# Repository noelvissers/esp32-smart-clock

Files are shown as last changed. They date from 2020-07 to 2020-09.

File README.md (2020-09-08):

# Smart Clock





The 'Smart Clock' is a clock that displays time, date and weather information. It can auto change display brightness and almost everything is configurable (like 12-hour or 24-hour clock, temperature in °C or °F, date in days-months or months-days format and automatic or manual brightness control).  
Hardware files are made in Altium and software is written in C++.

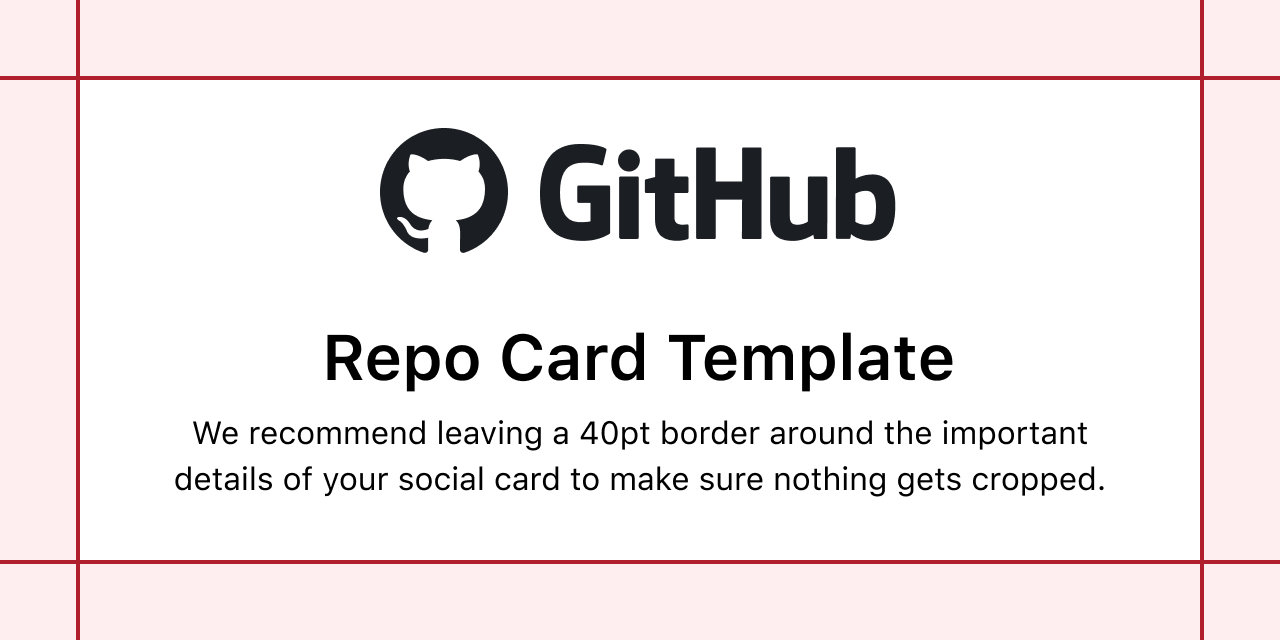
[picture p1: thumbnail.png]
Smart Clock


'Smart Clock' is a project I started years ago with an idea for my Arduino Nano after seeing [this](https://www.instructables.com/id/Making-a-Wooden-LED-Clock/) project. I got the basics to work but wanted to expand and improve on this idea.
A lot more was possible with wifi integration on the ESP32, so that's what made me pick up this project again. I'm most interested in hardware (that's also what I studied) but during this project I learned a lot about C++ in general, so it was a good learning experience. I know the code can get a lot cleaner if I remove some global vars and structure some things a bit different, but I found a lot of that out while already being pretty far into the project. Maybe something to change in the future, but not for now.

## Table of content
- [Project directories](#project-directories)
- [Features](#features)
- [Software](#software)
  * [Language](#language)
  * [IDE and framework](#ide-and-framework)
  * [Libraries](#libraries)
  * [Documentation](#documentation)
- [Hardware](#hardware)
  * [Components](#components)
  * [PCB](#pcb)
- [Case](#case)
- [Wish list](#wish-list)

## Project directories
### `/hardware`
This directory includes all the hardware files used in this project. The .pdf files of the Smart Clock schematic and PCB design are located in the main folder. The original Altium Designer files and gerber files are located in the sub folders.
### `/include`
The include directory contains all the header files needed for this project. 
### `/src`
The src directory contains all the `.cpp` files needed to run this project, including the `main.cpp` file.

## Features
I called this project 'Smart Clock' but what does this exactly mean for this project? The clock is 'smart' in a way that it does a lot of things automatically, without the need of any user input. This results to the following features: 
- Displaying time and weather information   
Of course, the most important feature of a clock: Displaying the time. Besides displaying time, the Smart Clock can display date, temperature, humidity and time with date in binary (when enabled and always in 24H format).   
   
   ![Different modes gif]()   

- Automatic network configuration:   
The clock can automatically connect to a saved wifi network. When there is no network configured, it sets up its own network to connect to via your PC, tablet or phone. A new wifi connection can be configured in the portal that shows up after connecting. The settings of the clock can also be configured in this portal as shown below:   
   
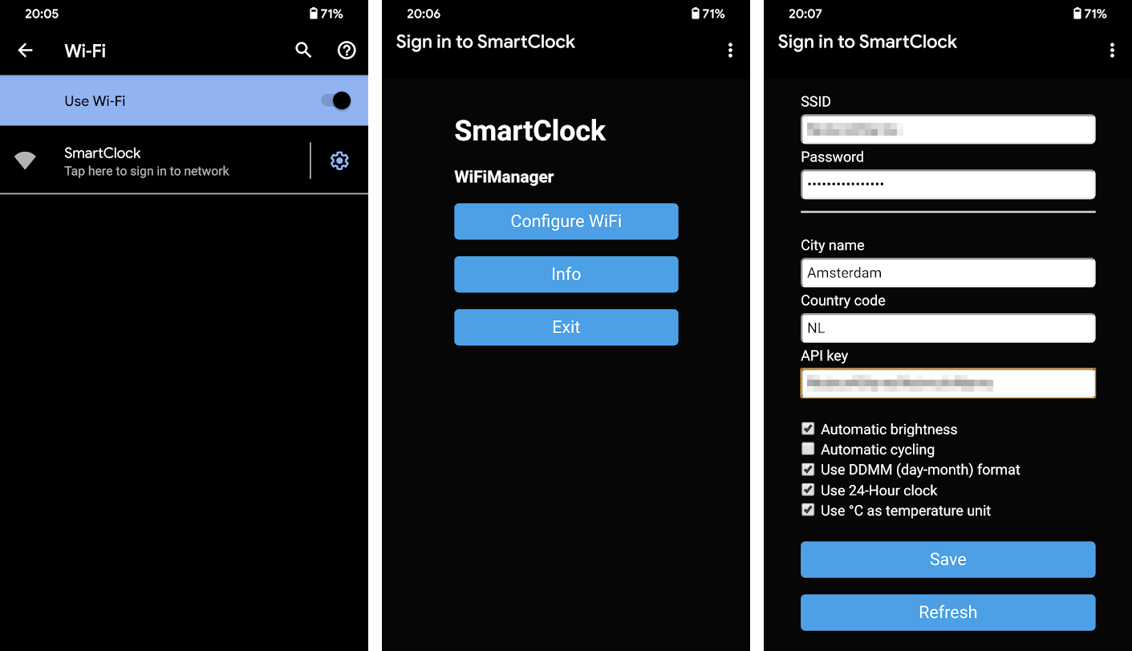
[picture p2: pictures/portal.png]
Configuration portal
      

- As shown in the portal, the clock has a lot of different settings:
   - **Auto brightness**: Automatically change the brightness of the matrix display depending on the light level in the room. This can also be manually controlled with the buttons on top of the clock (this will disable auto brightness and can be enabled again by holding the '+' button). Sensitivity can be adjusted in software, and with the potentiometer on the PCB.
   - **Auto cycling**: Auto cycle between the different screens like time, date and weather information. This can also be manually done by pressing the middle button on the clock. Doing this will disable auto cycling. To enable this again, hold the '-' button.
   - **Clock format**: Choose between 12-hour or 24-hour clock format.
   - **Date format**: Choose between Day-Month format or Month-Day format.
   - **Temperature unit**: Choose between °F or °C. 
   - **City/Country**: Get accurate weather information from your specified location. Check the available locations and valid format [here](https://openweathermap.org/).
- The RTC is synced with the web. This means if for some reason the RTC gets out of sync, the right time is set based on your [IP/location](http://worldtimeapi.org/api/ip).   

## Software
### Language
This project is written in C++ on the Arduino framework using PlatformIO. 
### IDE and framework
- [Visual Studio Code](https://code.visualstudio.com/) (Free)
- [PlatformIO for VSCode](https://platformio.org/install/ide?install=vscode) (Extension for VSCode. This basically is a fancy Arduino IDE and I recommend it for everyone programming an Arduino or using the Arduino platform since it's way more user and debug friendly)
- [Tutorial for using PlatformIO with ESP32](https://docs.platformio.org/en/latest/tutorials/espressif32/arduino_debugging_unit_testing.html)
### Libraries   
Libraries are automatically downloaded when building the project. They are defined in `platformio.ini`.
- [LedControl](https://github.com/gordoste/LedControl)
- [ArduinoJson](https://github.com/bblanchon/ArduinoJson)
- [RTClib](https://github.com/adafruit/RTClib)
- [WiFiManager](https://github.com/tzapu/WiFiManager#development) (development branch)
### Documentation
See comments in source files for the explanation of the code. If you have any questions about the code, or anything else, you can make an [issue](https://github.com/noelvissers/esp32-smart-clock/issues) and I'll try to answer it as soon as I can.

## Hardware
The whole project is built on the ESP32. The board I used is the [ESP32-DevKitC V4](https://docs.espressif.com/projects/esp-idf/en/latest/esp32/hw-reference/esp32/get-started-devkitc.html). This microcontroller is easy to use (uses the Arduino framework) and has built-in bluetooth and wifi connectivity. This controller also has two cores which is very useful in some situations.
### Components   
NEEDS UPDATING!!!   
- [ESP32-WROOM-32D](https://aliexpress.com/item/4000103411061.html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,searchweb201602_,searchweb201603_)
- [Micro USB cable extender](https://aliexpress.com/item/32859863965.html?spm=a2g0s.9042311.0.0.27424c4du3jPcB)
- [USB C (F) to micro USB (M)](https://aliexpress.com/item/33004521025.html?spm=a2g0s.9042311.0.0.27424c4du3jPcB)
- 2x [Matrix display 8x8 + MAX7219](https://aliexpress.com/item/4000263982956.html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,searchweb201602_,searchweb201603_)
- 2x [Narrow 24 pin DIP socket](https://aliexpress.com/item/32866573215.html?spm=a2g0s.9042311.0.0.27424c4dnmoTWS)
- 4x [1x8 Matrix header](https://aliexpress.com/item/32847506950.html?spm=a2g0s.9042311.0.0.27424c4dnmoTWS)
- [DS3231 RTC](https://aliexpress.com/item/32822420722.html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,searchweb201602_,searchweb201603_)
- [3V3 - 5V level shifter](https://aliexpress.com/item/1972789887.html?spm=a2g0s.9042311.0.0.27424c4dnmoTWS)
- [2x10 2.54mm 90 degree Male header](https://aliexpress.com/item/32683792015.html?spm=a2g0s.9042311.0.0.27424c4dnmoTWS)
- [2x10 2.54mm  Female header](https://aliexpress.com/item/32864030298.html?spm=a2g0s.9042311.0.0.27424c4dnmoTWS)
- [5528 LDR](https://aliexpress.com/item/32760631393.html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,searchweb201602_,searchweb201603_)
- [<value> Potentiometer for LDR adjustments](https://aliexpress.com/item/4000109378348.html?spm=a2g0s.9042311.0.0.27424c4dp3I9x0)
- 4x [5mm M3 standoff](https://aliexpress.com/item/32982370726.html?spm=a2g0s.9042311.0.0.27424c4dp3I9x0)
- 4x [4mm M3 screw](https://aliexpress.com/item/4000193782706.html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)
- \+ Other various components like resistors and capacitors (see schematic).

The electronics for this project are fairly simple. I choose to use TH components instead of SMD components (and in some cases breakout boards) since these are easier to solder and replace by hand. Since this is meant as a prototype, a later version would include SMD components, no breakout or developer boards and probably JTAG programming. But this is out of my scope for this project.   
   
For the schematic and other documentation, see the [/hardware](/hardware/smart-clock/smart-clock) folder.

### PCB
Below you can see (from left to right) the top, front and side view of the PCB.   
   
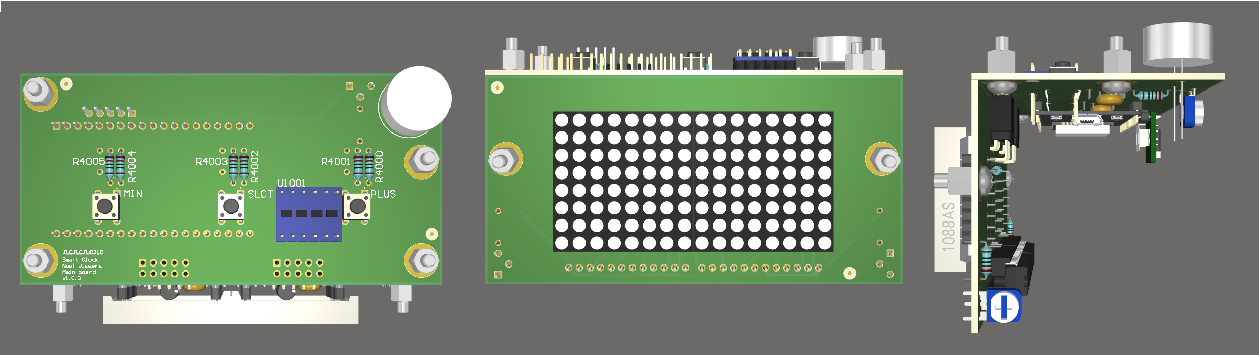
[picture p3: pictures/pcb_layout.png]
PCB
   
   
The gerber files to order the PCB are located in the designated hardware folder.
   
## Case
To see what would go where (on the PCB as well as the mechanical design) I created a [mechanical sketch](/pictures/mch_sketch.png) (yes, in paint).   
   
After this, I could make the PCB and a real mechanical drawing to figure out actual sizes of the case:   
   
MCH design   
   
After I was happy with how everything turned out, I rendered the image to get a clear view of what the end result would be like:   
   
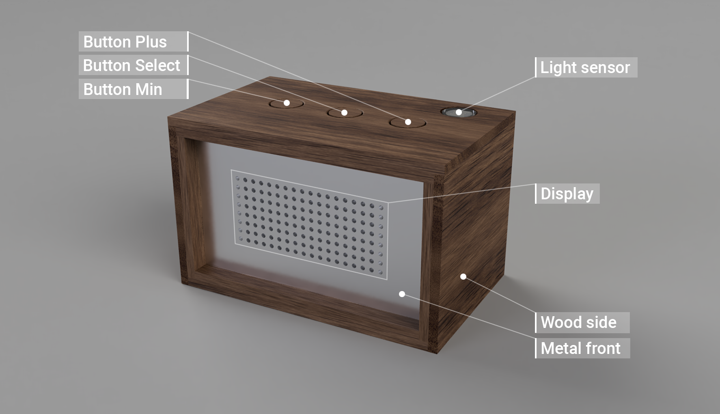
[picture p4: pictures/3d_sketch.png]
3D render
   
   
Note that there is a 8x18 grid of holes in the case, while the display is only 8x16 pixels. This (in my opinion) looks better if a digit is displayed on the edge of the display.
   
After having all the files, the PCB, all hardware components, and the software done, it was time to finish this project (v1). 

### End result
Result   

## Wish list
These are features I don't expect to implement in this version, but that could be nice for a future update.
- [x] Have wifi configurable and not hard-coded.  
- [ ] Have all the components (SMD) on 1 PCB so the whole thing can be a lot smaller. This also means not using an ESP32 dev. kit (or any USB interface at all).  
- [ ] Have an app or better online portal to configure all the settings, whenever you want (not only on startup).  
- [ ] Auto detect location to configure weather or use location from app.
- [ ] Add audio support to add alarms/mp3 playback via app.   
- [ ] Add RGB display and/or more displays, to be able to implement more features (like LaMetric Time).
- [ ] Clean up the code a lot.   
   
Feel free to submit any issues and/or pull requests if you have new idea's or run into issues. Of course, you are also free to implement idea's I mentioned.

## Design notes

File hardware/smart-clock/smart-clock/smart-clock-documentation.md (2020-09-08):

# Circuits
Below are the hardware circuits for the clock explained. If you have any questions about the circuits, or anything else, you can make an [issue](https://github.com/noelvissers/esp32-smart-clock/issues) and I'll try to answer it as soon as I can.   

Below you can see the two PCB projects, since we need two PCB's to make this clock. This is becuase the display is at a different angle (see [PCB](#pcb)).   
   
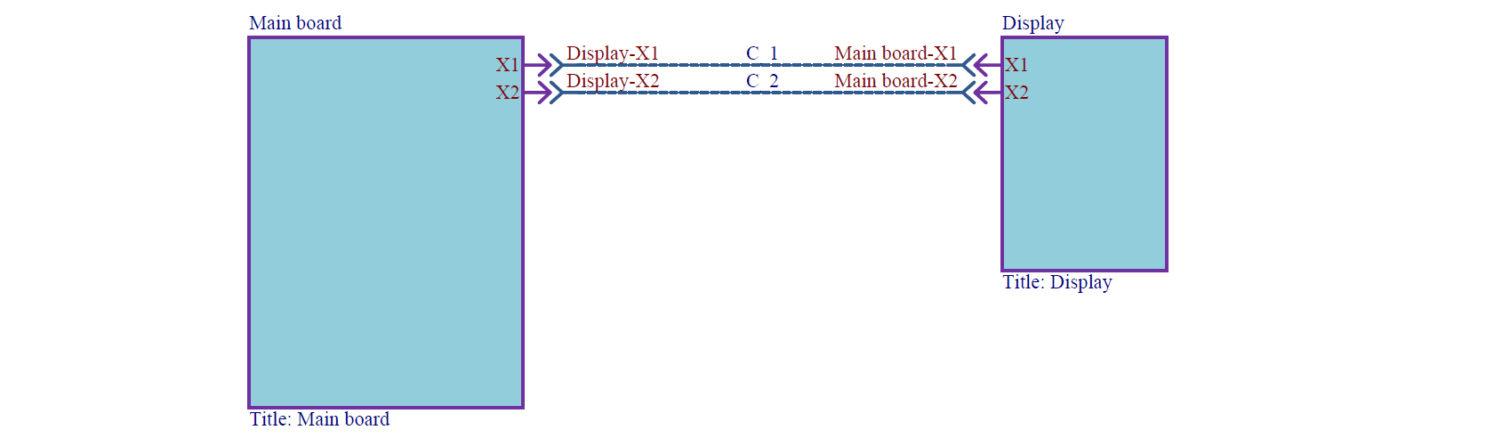
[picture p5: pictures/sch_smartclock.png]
SCH
   
   
Below you can see the schematic (blocks) for the main board. This is where most components are (outside the display). The buttons, RTC and LDR are all connected to the microcontroller, the ESP32, and the microcontroller is connected to the header that connects to the display PCB. X1 is just there for support. Note that there is no power input anywhere in these schematics. The power comes from the ESP32's USB port. This will be showed later in the mechanical design.   
   
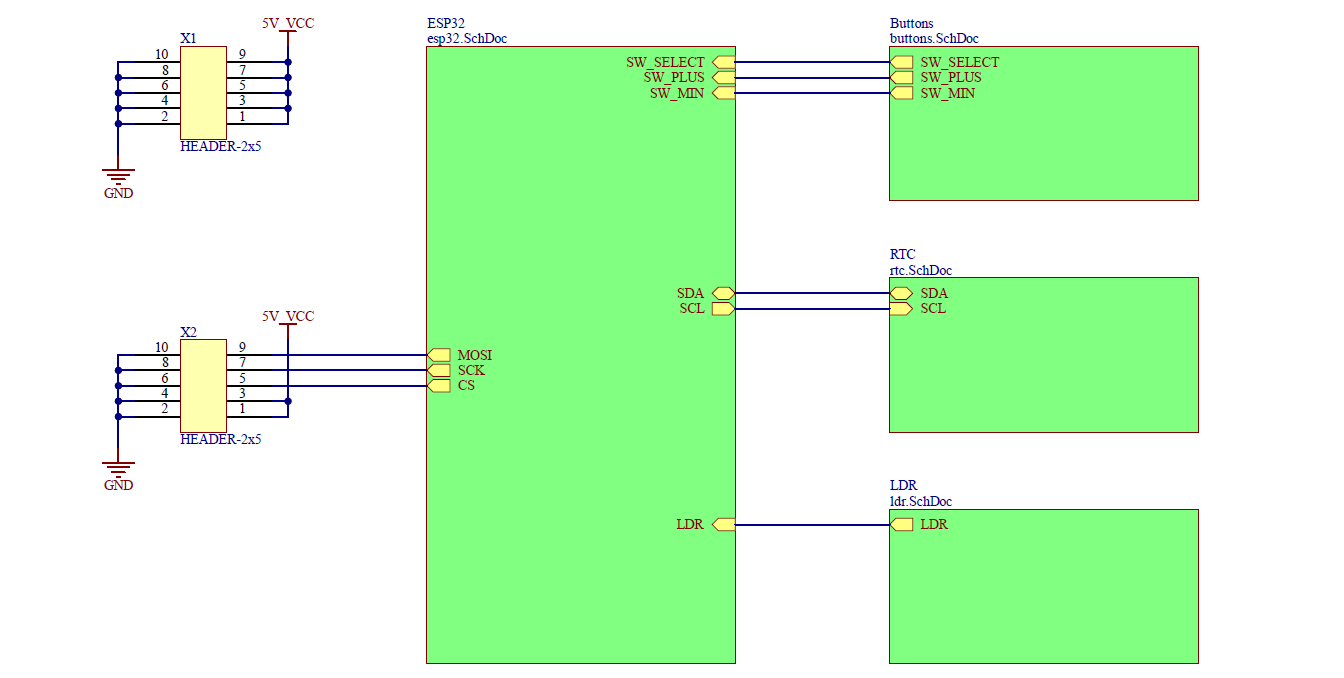
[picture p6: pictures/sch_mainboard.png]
SCH base board
  
## ESP32
This is the heart of the clock; the microcontroller a.k.a. the ESP32. Since it the operating voltage of the microcontroller is 3.3V, the normal 5V USB voltage won't be suited. On the devkit there is a voltage regulator to bring down the 5V to 3.3V, but there is still a pin we can use that is connected to the 5V input. This means we can drive the 5V display from this USB power. For the data lines we need a level shifter (U1001). This means the ESP can send on 3.3V and the MAX7219 will receive this as 5V. 
   
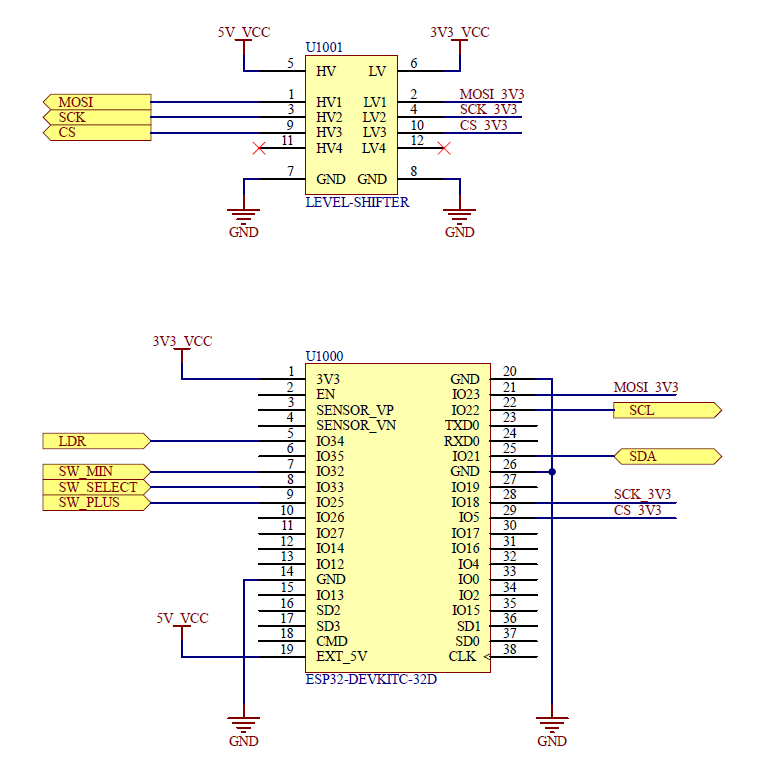
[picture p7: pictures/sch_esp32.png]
ESP32
   

## Buttons
For the buttons I used a simple debounce circuit. In testing I found out that this sometimes doesn't filter out all the bouncing, so this is also handled in software. This could be because of bad buttons or wrong resistor/capacitor values, but the solution I found in software with interrupts works very smooth right now. Having a pull-up resistor to 3.3V means the button is active LOW.   
   
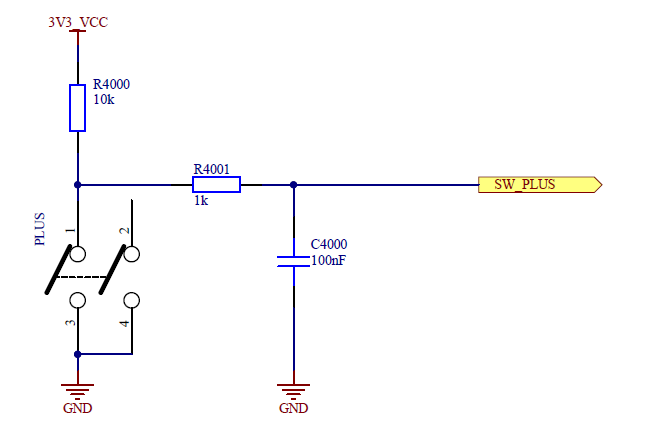
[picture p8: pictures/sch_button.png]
Buttons schematic
   

## RTC
To keep track of the time, even when the clock is powered off, we need a RTC. The DS3231 RTC used in this project communicates via I2C. This means we need 4 pins connected to the ESP: SDA, SCL and GND/VCC. The DS3231 has a [typical input voltage of 3.3V](https://datasheets.maximintegrated.com/en/ds/DS3231.pdf) which is perfect since the ESP runs on 3.3V. This also means there is no level shifter needed for the data and clock lines. Since the ESP32 has dedicated I2C pins, we can use these to communicate with the RTC. These are pin IO21 (SDA) and IO21 (SCL).   
   
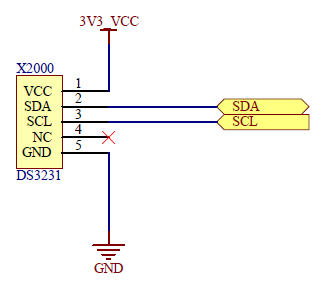
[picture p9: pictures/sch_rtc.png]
RTC schematic
   

## LDR
This is a simple voltage divider. The resistance of the LDR changes depending on the light level; more light means less resistance. This means the voltage to the analog input of the ESP changes; a higher voltage level with more light, a lower voltage level with less light. The sensitivity can be set with the potentiometer. Since this is an analog output, we need to make sure it is connected to an analog input on the ESP so we can use the ADC from the ESP to read this value.    
   
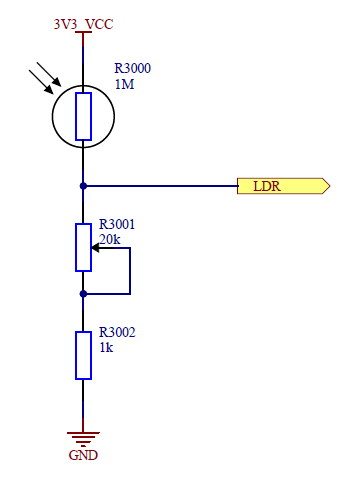
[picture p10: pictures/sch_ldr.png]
LDR schematic
   

## Display
The dot matrix displays are powered via the [MAX7219 display driver](https://datasheets.maximintegrated.com/en/ds/MAX7219-MAX7221.pdf) on 5V. Since the ESP developer board is powered by USB (5V), we can use the input voltage of the board to power the MAX7219. The other parts of ESP run on 3.3V, so we need a level shifter for the 3 data lines: D<sub>IN</sub>, CS and CLK. The CS and CLK lines go to both display 1 and 2, while the data line (D<sub>IN</sub>) only goes to display 1. The MAX7219 has a data out (D<sub>OUT</sub>) pin that can be connected to the data in pin of display 1. This way we can daisy chain the displays together.   
The I<sub>SET</sub> resistor sets the maximal current for the display. This means you will get less brightness with a higher resistor value. I found that the typical circuit that uses around 10kOhm is way too bright, especially at night. You might want to experiment with this a bit and see what value you prefer. In [this video](https://www.youtube.com/watch?v=MT4PSEJzVU0) you can see the effect of different resistor values, although a camera always tries to compensate for this light level. This video does however give a good indication of the minimum brightness. I used a 100k potentiometer in series with the recommended 10k resistor, so I can tweak it after assembly, where 10k is too bright and 100k (or 110k in this case) is probably too dark. So somewhere in the middle should be the sweat spot.   
   
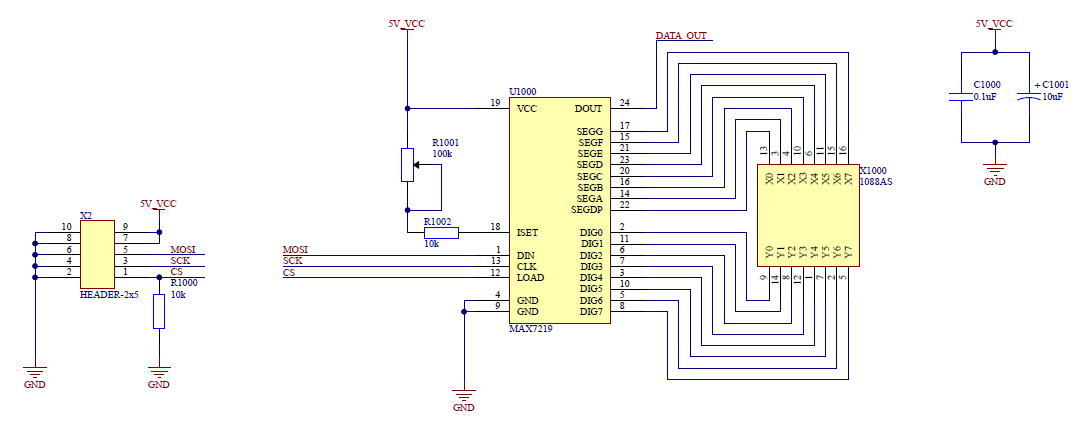
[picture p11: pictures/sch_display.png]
Display schematic
   

# Testing
Testing all the hardware (and also software). This is to check if all the circuits work as intented.   
   
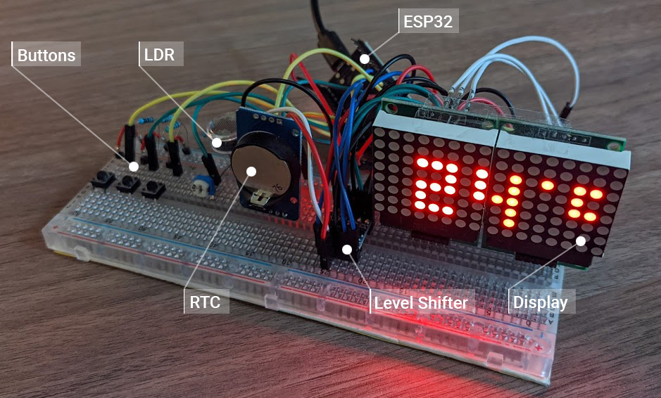
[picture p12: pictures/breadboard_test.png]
Breadboard testing
   
   
As you can see, the right display has a different brightness. During the testing phase, I found out the display can actually get pretty bright and also blinding. So I expirimented with different resistor values.

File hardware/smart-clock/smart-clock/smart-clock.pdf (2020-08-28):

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
1 | 1
2 | 2
3 | 3
4 | 4

Main board

Title: Main board

Display

Title: Display

X1 | X1
X2 | X2
Display-X1 | C_1 | Main board-X1
Display-X2 | C_2 | Main board-X2

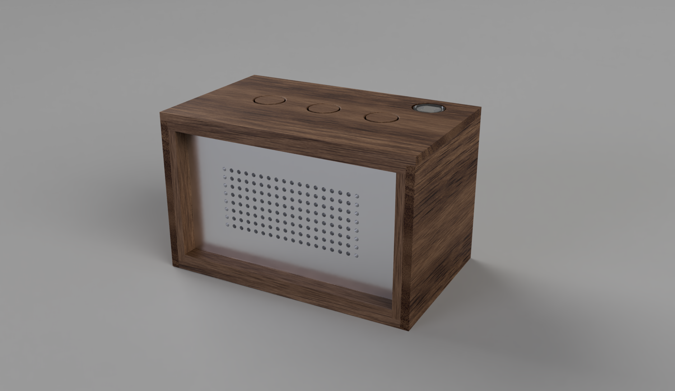
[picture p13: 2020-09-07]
pictures/3d_render.PNG

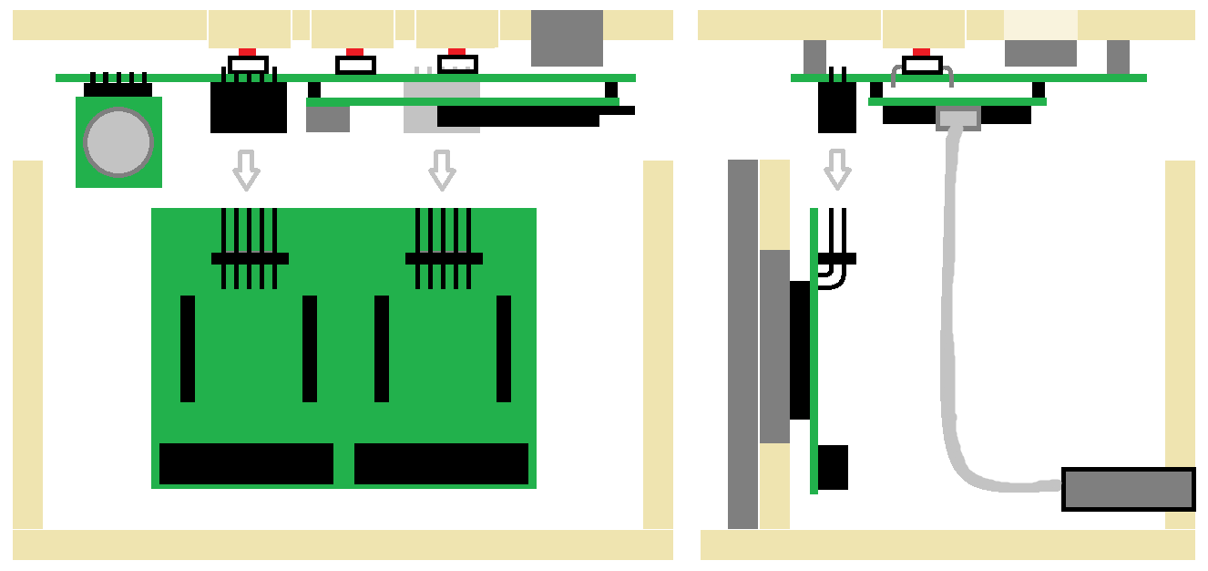
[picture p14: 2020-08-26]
pictures/mch_sketch.png

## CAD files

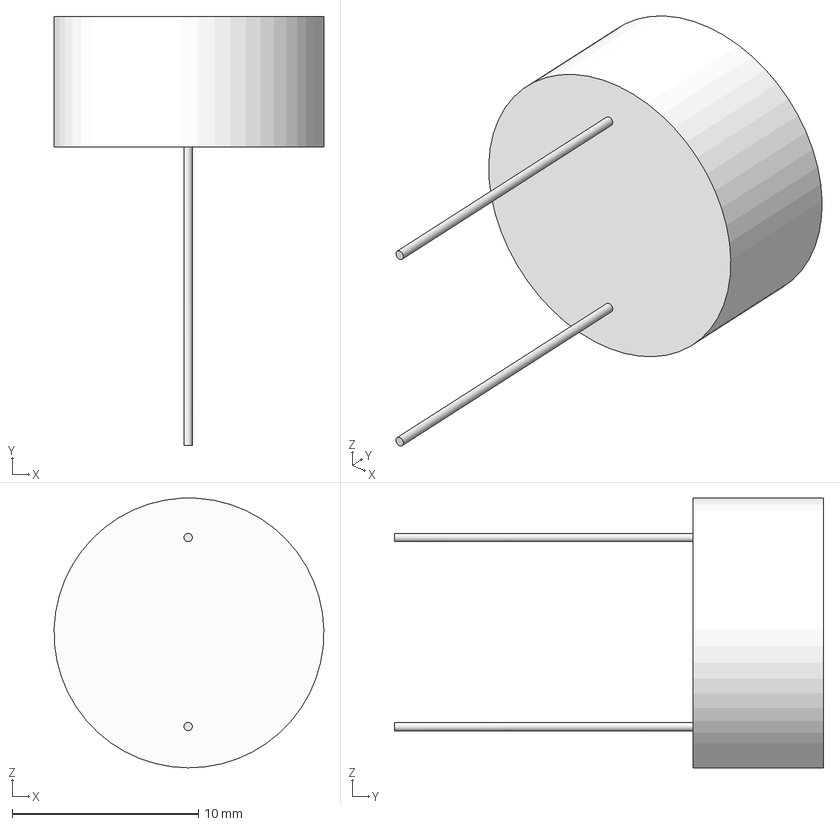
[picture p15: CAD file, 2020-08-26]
hardware/smart-clock-library/3d-files/TH LDR.step
14.5 x 23.1 x 14.5 mm
Ceramic base^LDR cell thru-hole leaded
Electrodes^LDR cell thru-hole leaded
Leads^LDR cell thru-hole leaded

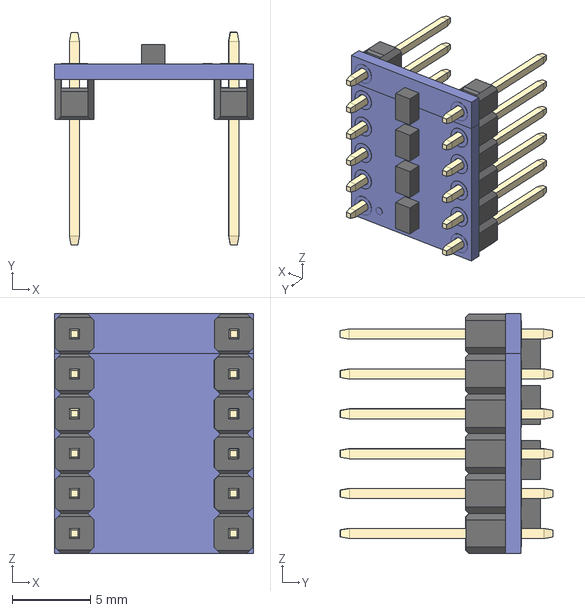
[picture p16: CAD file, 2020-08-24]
hardware/smart-clock-library/3d-files/LEVEL SHIFTER.step
12.7 x 13.6 x 15.3 mm
1x5 Male Pin Header x 2

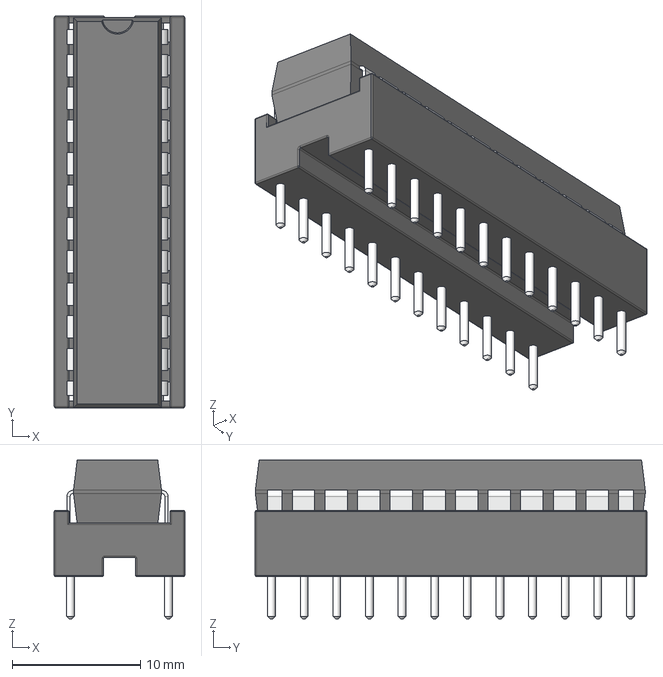
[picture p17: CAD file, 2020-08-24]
hardware/smart-clock-library/3d-files/MAX7219.step
10.2 x 30.5 x 12.4 mm
MAX7812 with DIP
MS-001BE

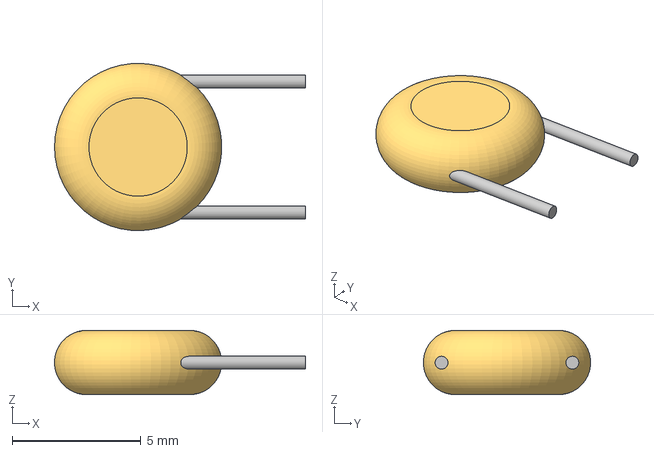
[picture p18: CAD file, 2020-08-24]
hardware/smart-clock-library/3d-files/TH Capacitor - 0.1uF.step
9.75 x 6.49 x 2.50 mm

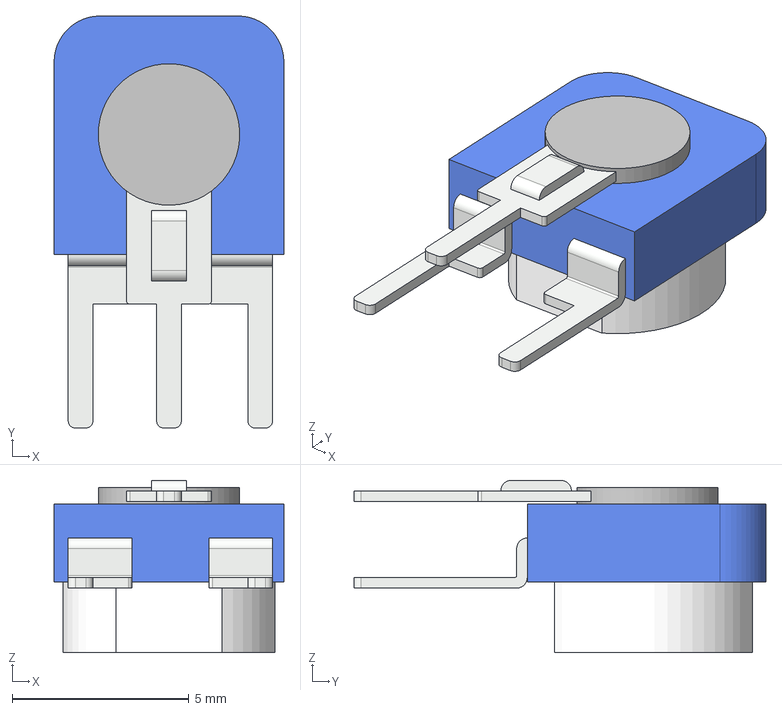
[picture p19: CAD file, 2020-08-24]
hardware/smart-clock-library/3d-files/TH Potmeter.step
6.50 x 11.7 x 4.87 mm

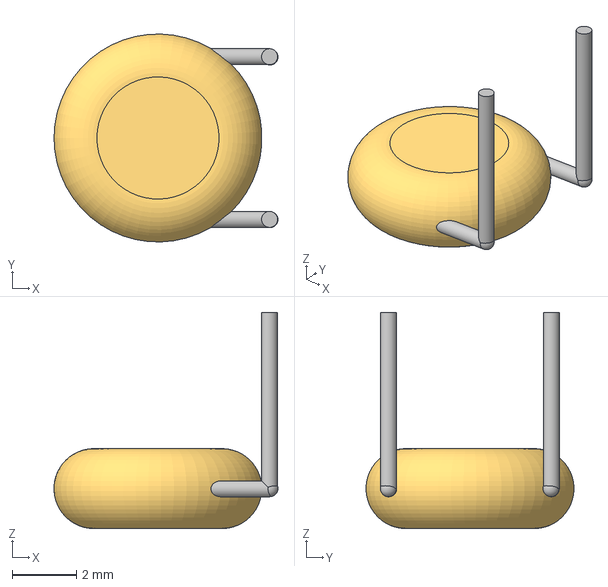
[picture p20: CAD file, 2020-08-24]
hardware/smart-clock-library/3d-files/TH Capacitor - Angle.step
7.00 x 6.49 x 6.75 mm

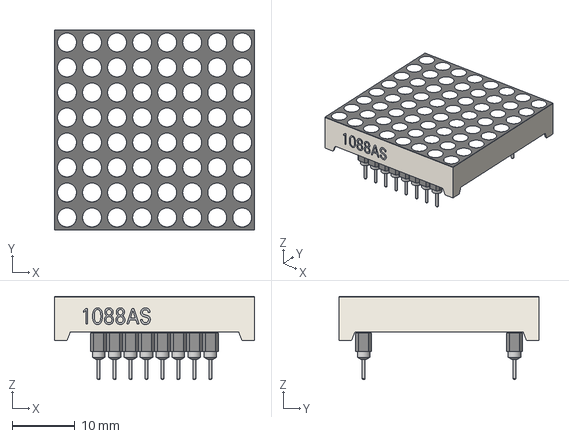
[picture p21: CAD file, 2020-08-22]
hardware/smart-clock-library/3d-files/8x8 LED Dot Matrix Display Module.step
31.8 x 31.8 x 13.2 mm
1088AS
8x female rounded header x 2

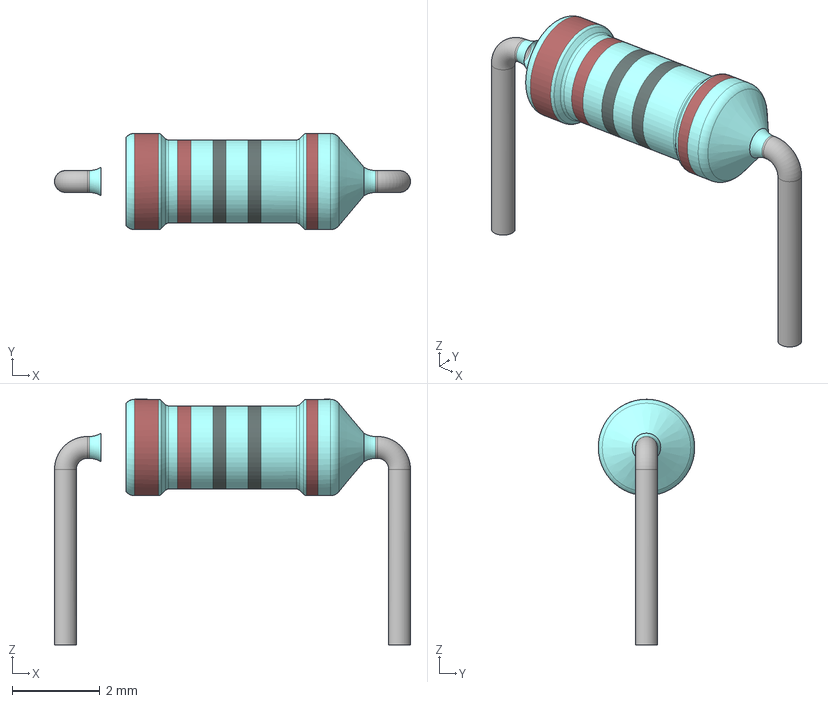
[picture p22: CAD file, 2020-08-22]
hardware/smart-clock-library/3d-files/TH Resistor - 10k.step
8.12 x 2.20 x 5.60 mm

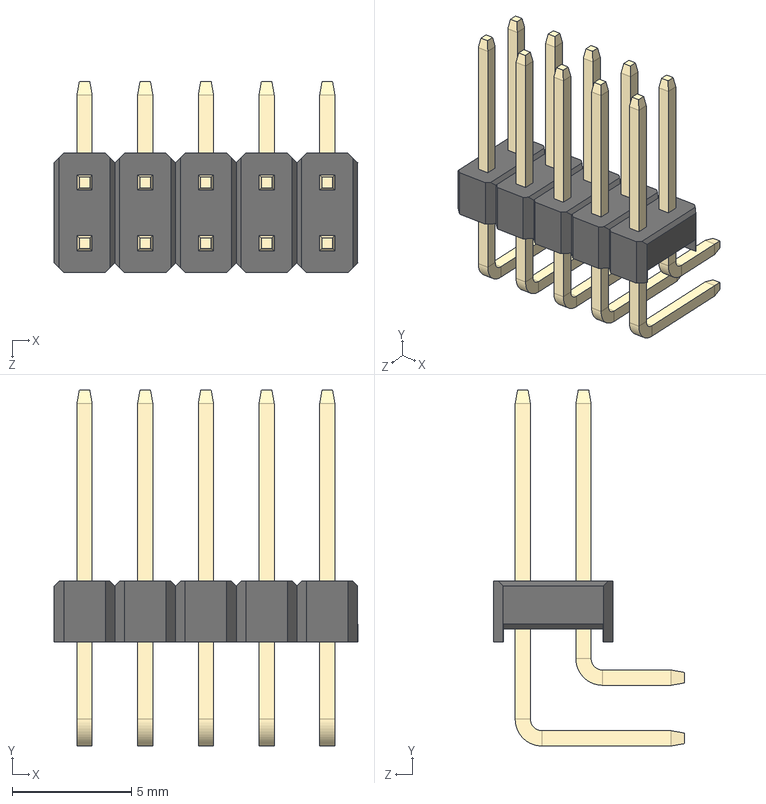
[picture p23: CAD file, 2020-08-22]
hardware/smart-clock-library/3d-files/2x5 Male Pin Header Angle.STEP
12.7 x 14.9 x 8.00 mm

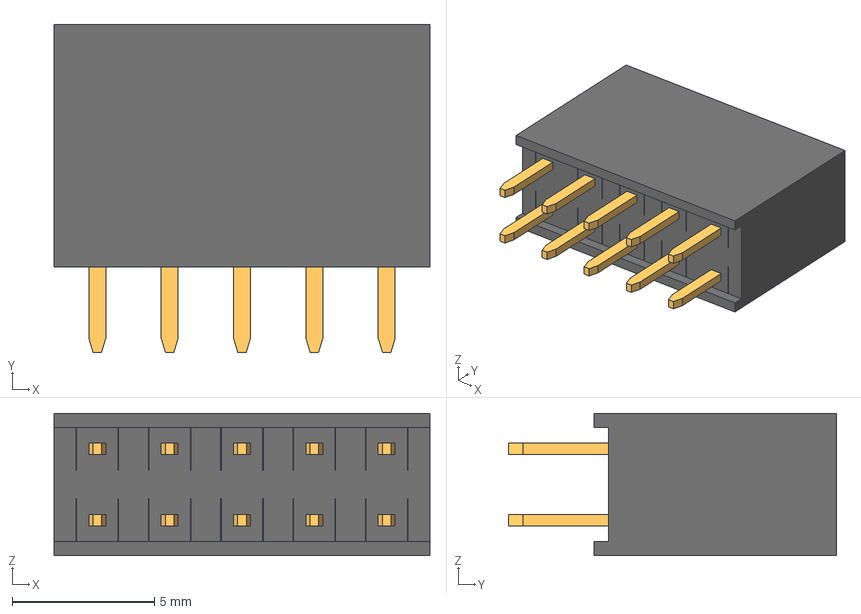
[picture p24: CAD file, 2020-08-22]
hardware/smart-clock-library/3d-files/2x5 Female Pin Header.stp
13.2 x 11.5 x 5.00 mm

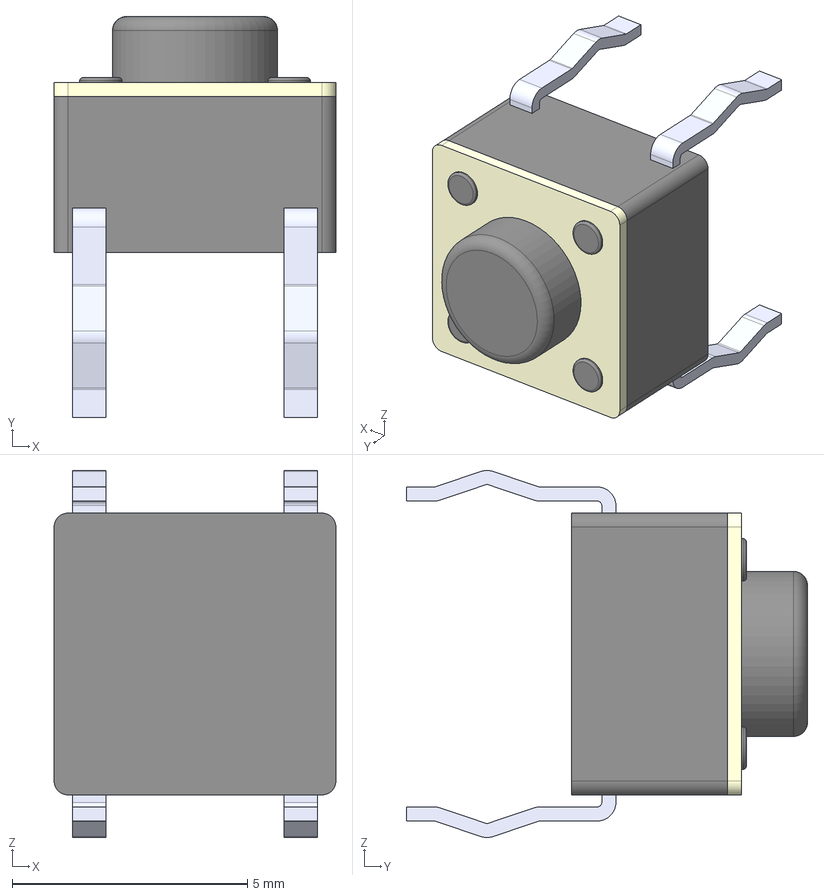
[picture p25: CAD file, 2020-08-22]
hardware/smart-clock-library/3d-files/TH Pushbutton.step
5.99 x 8.52 x 7.80 mm

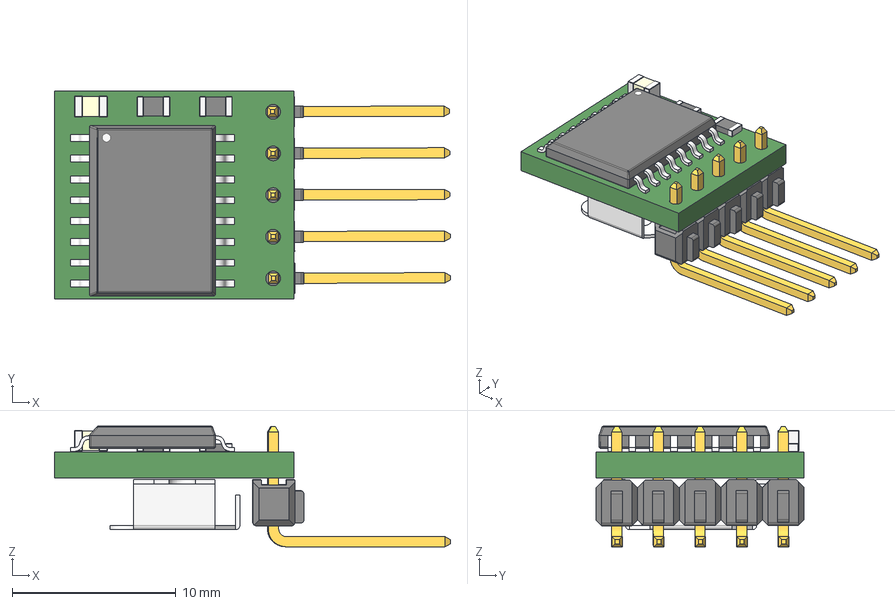
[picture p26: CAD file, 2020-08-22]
hardware/smart-clock-library/3d-files/DS3231 Mini.step
24.2 x 12.7 x 7.37 mm
Board_RTC_3231_Mini
cap_0805
res_0805 x 2
soic-16_300mil
Pin Header 1x5 TH Angle Pitch 2.54mm Copy Copy

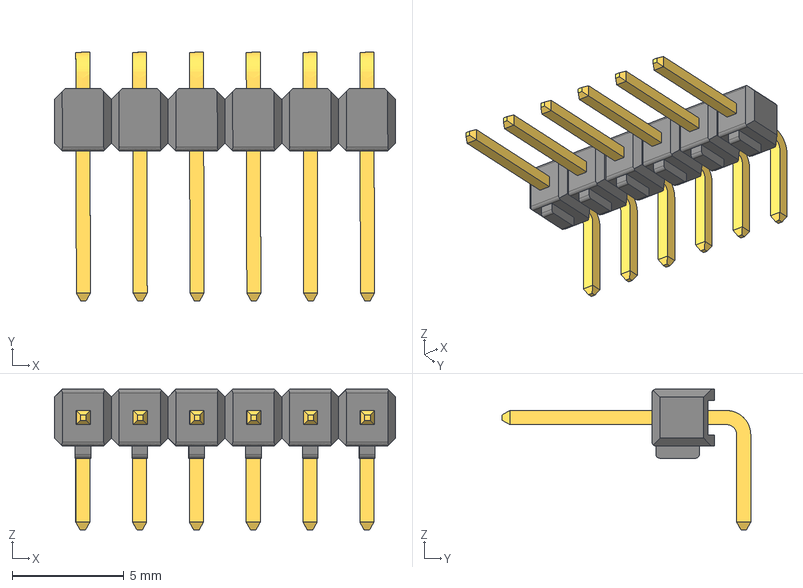
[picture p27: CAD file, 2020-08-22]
hardware/smart-clock-library/3d-files/1x6 Male Pin Header Angle.stp
15.2 x 11.1 x 6.29 mm

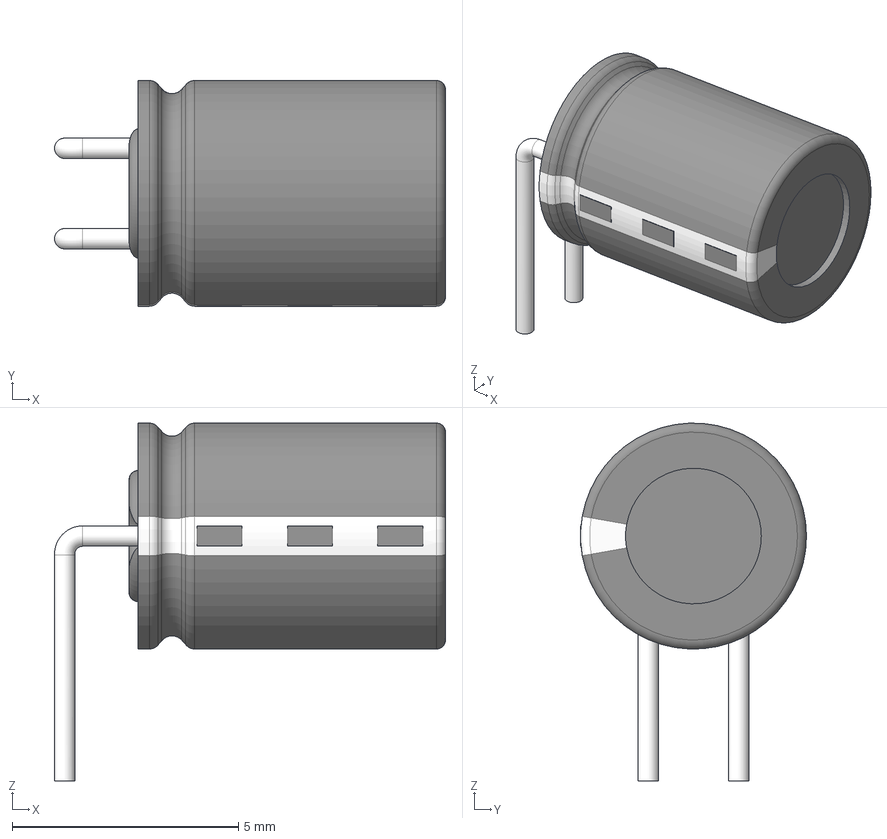
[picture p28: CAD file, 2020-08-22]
hardware/smart-clock-library/3d-files/TH Capacitor - 1uF.step
8.65 x 5.00 x 7.91 mm

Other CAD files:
hardware/smart-clock-library/3d-files/M3 Spacer Male-Female - 5mm Height x 3mm Thread.step
hardware/smart-clock-library/3d-files/2x10 Male Pin Header Angle.STEP
hardware/smart-clock-library/3d-files/1x5 Male Pin Header.STEP
hardware/smart-clock-library/3d-files/M3 Screw - 5mm.step
hardware/smart-clock-library/3d-files/M3 Screw - 4mm.step

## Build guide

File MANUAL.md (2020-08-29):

# Manual

## Powering the Smart Clock   
The clock is USB powered via USB type C. Connect an USB cable to a power source (like a phone charger or USB port) and connect the USB type C connector to the back of the clock like shown below.   
![USB C connector]()   

## Setting up the Smart Clock   
1. To connect the ESP32 to a network, power the clock and wait for the status icon to appear:   
![Init status]()   
2. Meaning of status icons:   
![Status meaning]()   (what is what (wifi/time/weather) and what does the icon mean ⚪⦿●)   
3. When the network status is 'stuck' on this initializing, it means it couldn't connect to a saved network and it needs to be configured. To do this, open the wifi settings on your phone (or other device) and connect with 'Smart Clock'. Click to sign in to the clock and to open the portal:   
   
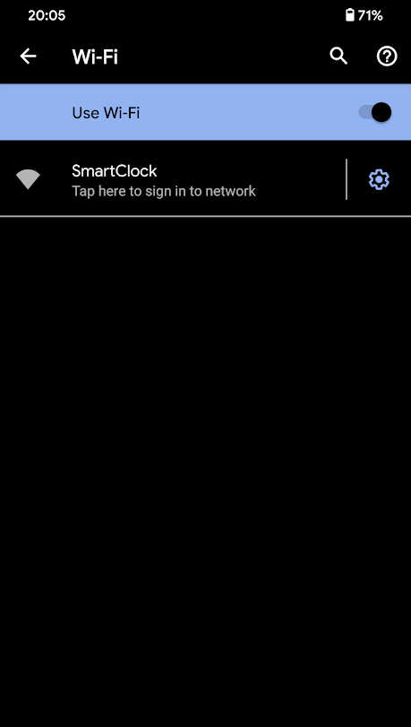
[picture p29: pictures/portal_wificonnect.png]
Portal login screen
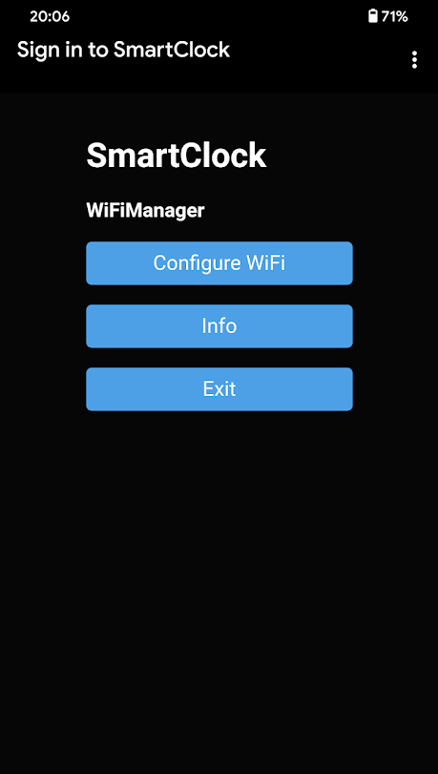
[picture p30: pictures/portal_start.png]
Portal config screen
    
   
4. Click on "Configure WiFi" to configure wifi and settings.   
5. Select the network you want to connect to and fill in the password:   
   
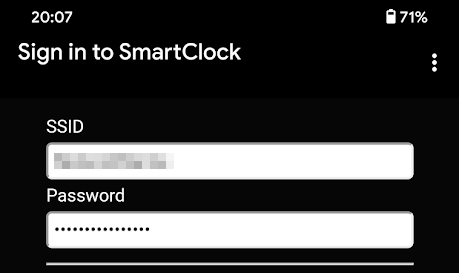
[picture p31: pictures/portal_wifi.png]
Portal wifi
   
   
6. Check the settings to your preference:   
   
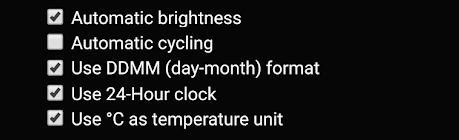
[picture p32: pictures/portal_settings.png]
Portal setup
   
   
7. Fill in your location and API key:   
    - **City**: The name of the city you want to get the weather data from (ex. Amsterdam). 
    - **Country code**: The country the city is in (ex. Netherlands).   
Valid location data can be found on the [OpenWeatherMap site](https://openweathermap.org/).
    - **API key**: Your OpenWeatherMap API key (see [here](https://openweathermap.org/appid) how to get an API key).   
    
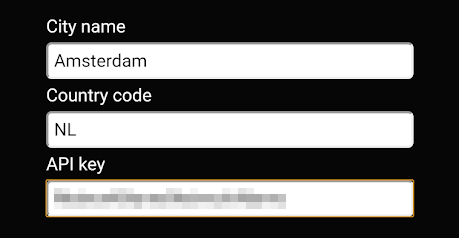
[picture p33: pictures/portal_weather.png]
Portal weather settings
   
   
8. Save your settings by pressing on save:   
   
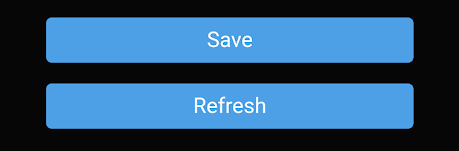
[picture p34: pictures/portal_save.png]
Portal save
   
   
After setting up your network, the clock should be configured and show the current time.   
   
## Buttons   
![Buttons]()   
`- | Min` Brightness level down (this disables auto brightness if enabled). Hold to enable auto cycling.   
`○ | Select` Cycle between time, date, temperature and humidity (this disables auto cycling if enabled). Hold (for 5 seconds) to reset clock (wipes settings and saved networks).   
`+ | Plus`  Brightness level up (this disables auto brightness if enabled). Hold (for 3 seconds) to enable auto brightness.

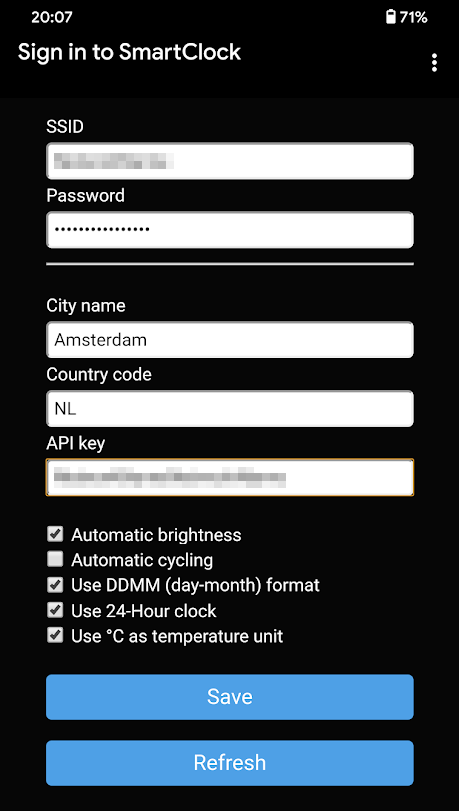
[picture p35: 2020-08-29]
pictures/portal_setup.png

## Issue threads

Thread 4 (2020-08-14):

Wifi portal opens even if credentials are known

noelvissers, 2020-08-14:
This happens sometimes. When you reboot, it takes the saved values again. This might be an issue with the WM library.

noelvissers, 2020-08-14:
Might be the same as this issue: https://github.com/tzapu/WiFiManager/issues/979

noelvissers, 2020-08-14:
fixedf in @c19bacd with retry

noelvissers, 2020-08-16:
was not fixed in @c19bacd with retry; disabling config portal does not work all the time, so retry is unreliable.

noelvissers, 2020-08-17:
This seems to be stable in latest push. Keeping this issue open in case it isn't stable yet.

noelvissers, 2020-08-18:
https://github.com/tzapu/WiFiManager/issues/1067

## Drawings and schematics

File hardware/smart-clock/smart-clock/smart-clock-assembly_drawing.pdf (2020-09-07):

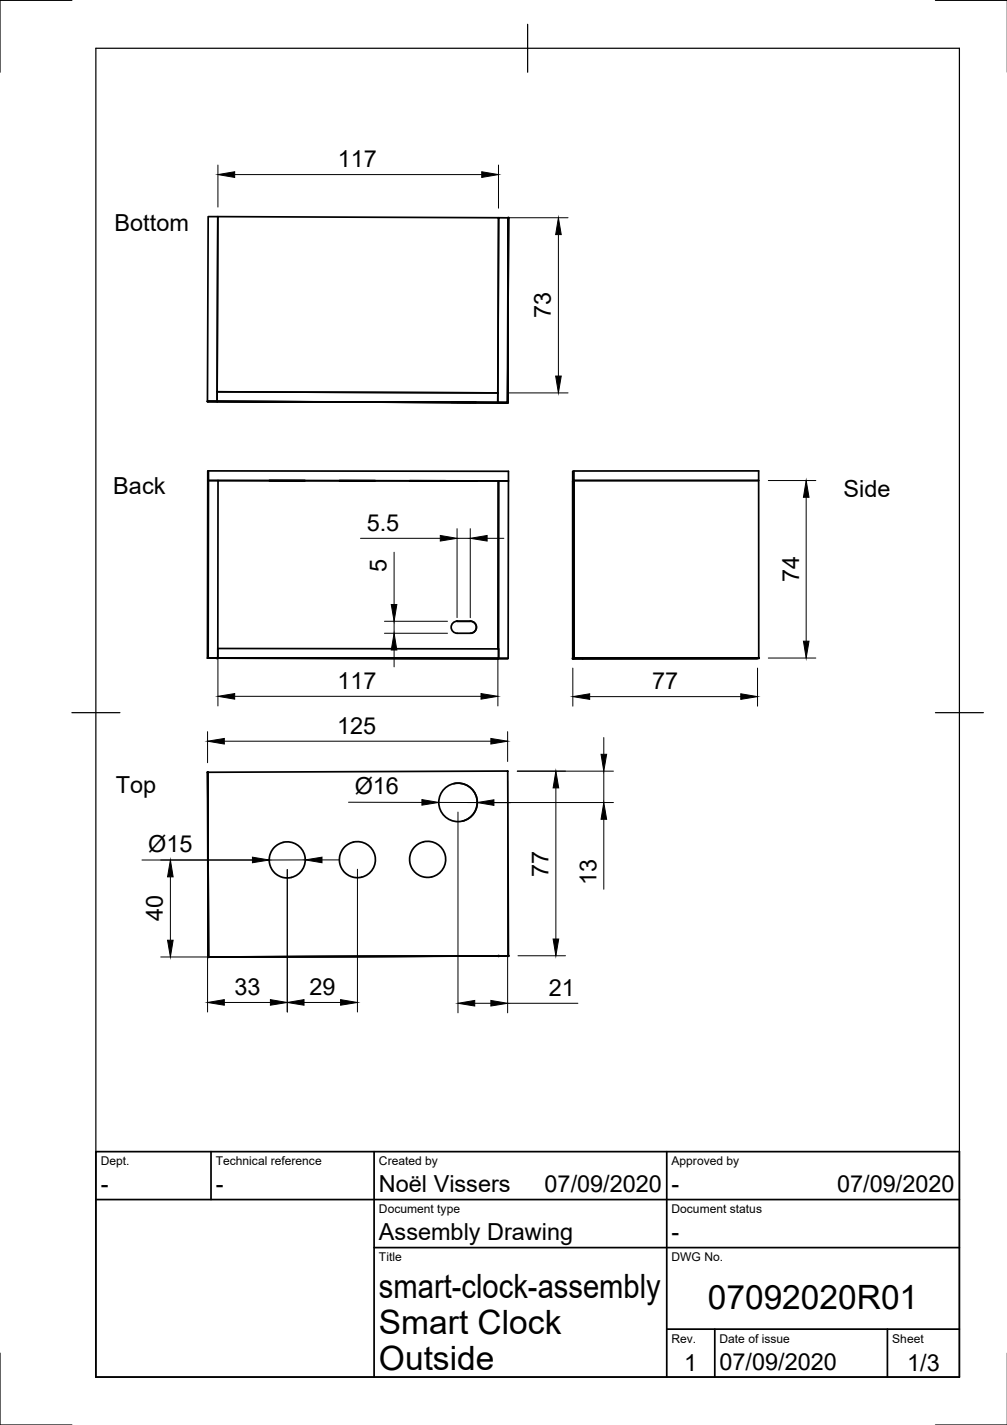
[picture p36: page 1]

Dept. - | Technical reference - | Created by Assembly Drawing Noël Vissers | Approved by - 07/09/2020 -07/09/2020

Document type | Document status

Title Smart Clock Outside | DWG No. 07092020R01 smart-clock-assembly

Rev. 1 | Date of issue 07/09/2020 | Sheet

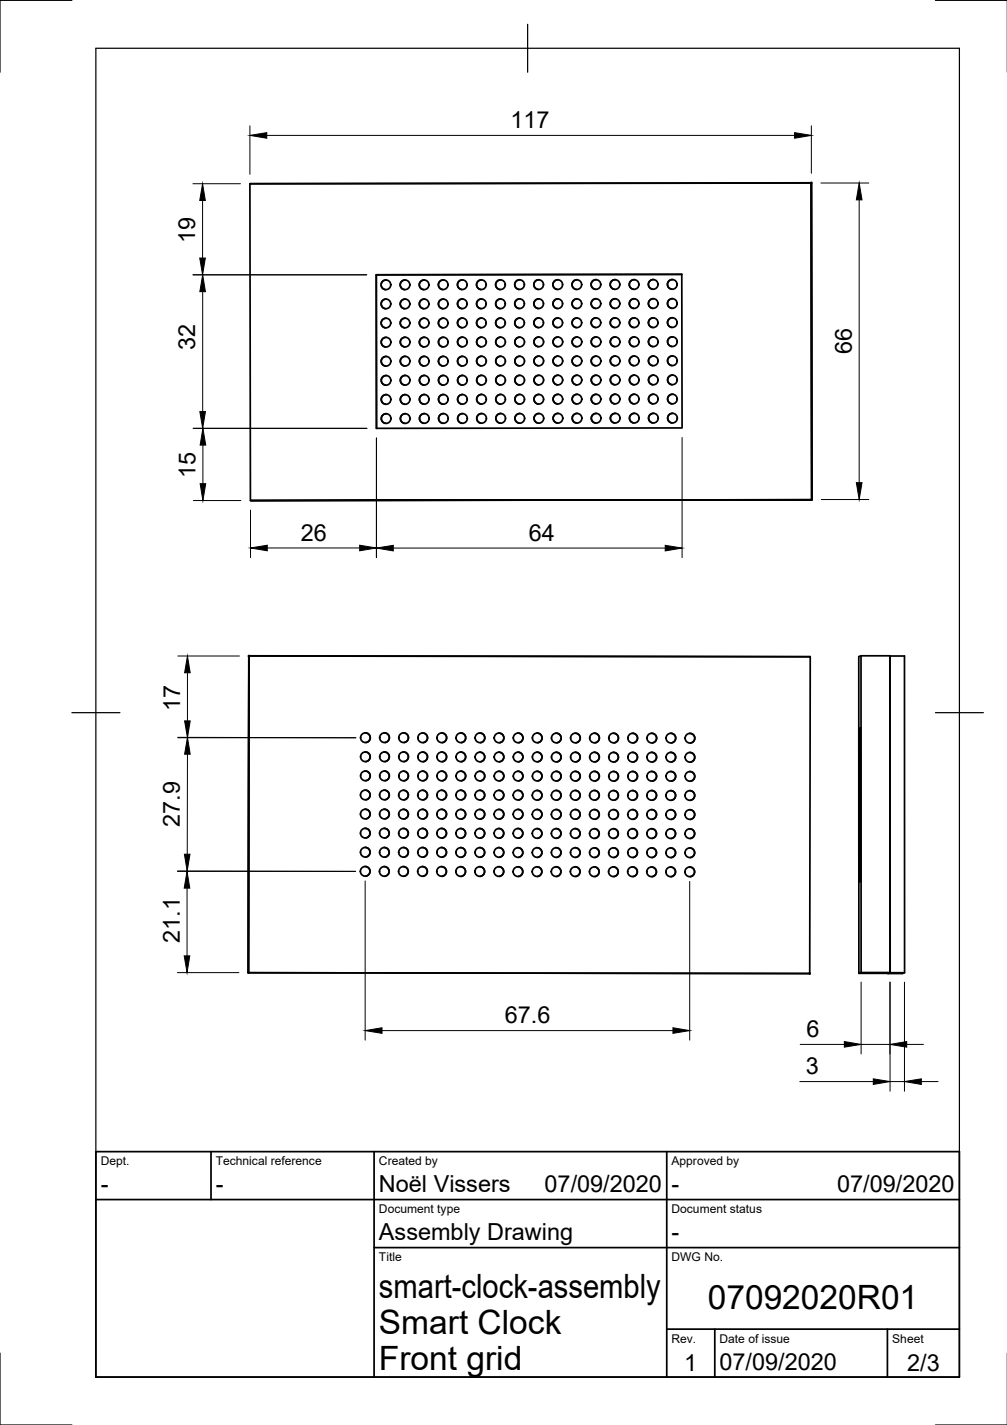
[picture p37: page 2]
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

Document type | Document status

Title Smart Clock Front grid | DWG No. 07092020R01 smart-clock-assembly

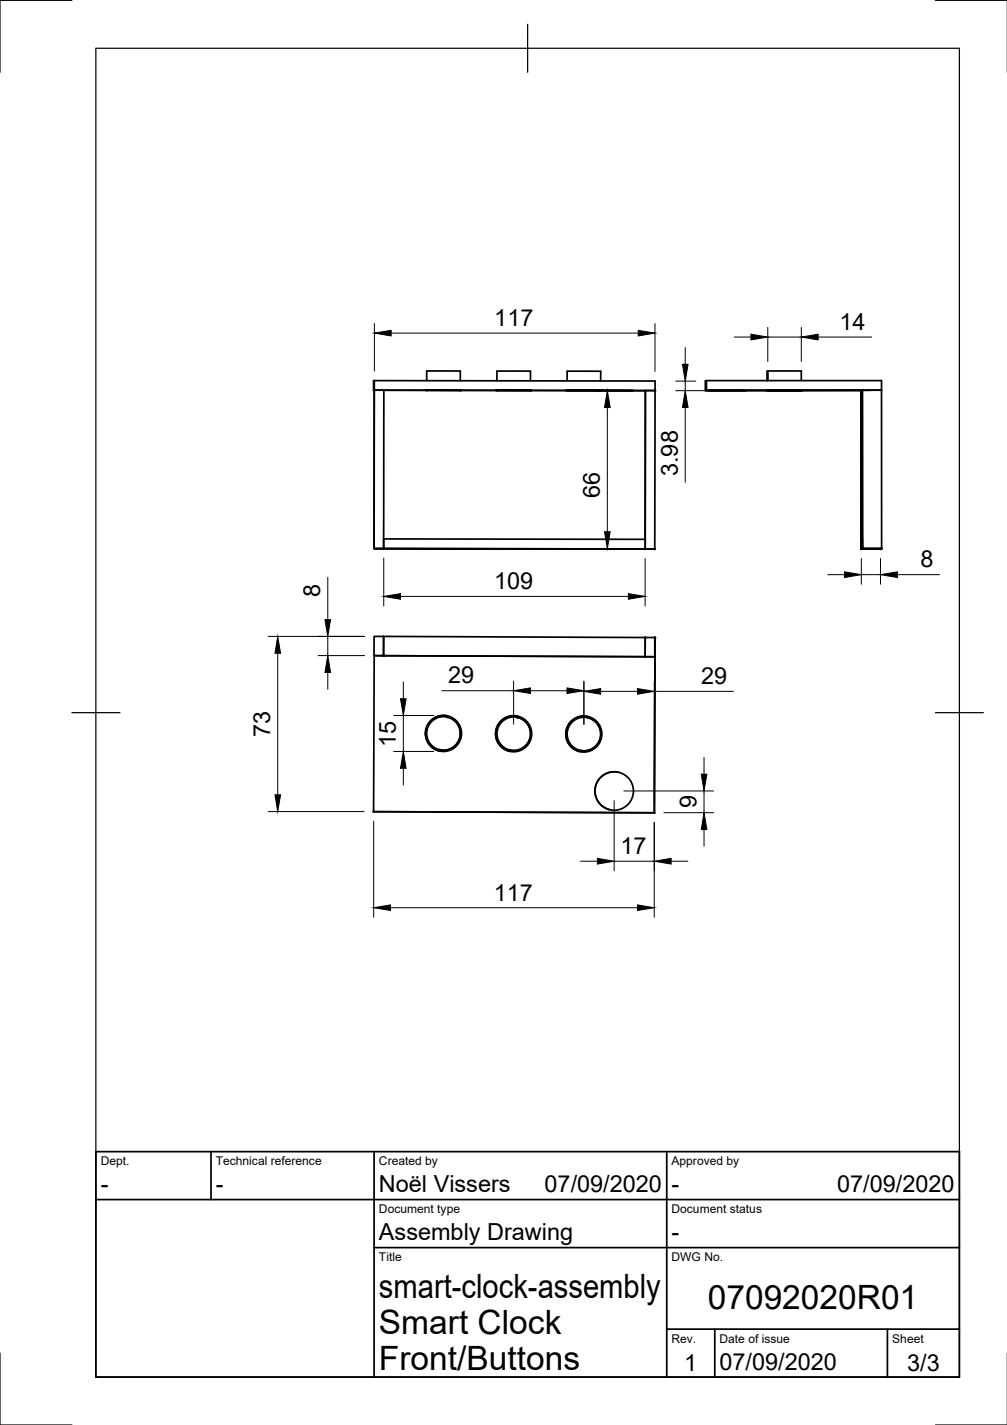
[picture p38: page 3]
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

Document type | Document status

Title Smart Clock Front/Buttons | DWG No. 07092020R01 smart-clock-assembly

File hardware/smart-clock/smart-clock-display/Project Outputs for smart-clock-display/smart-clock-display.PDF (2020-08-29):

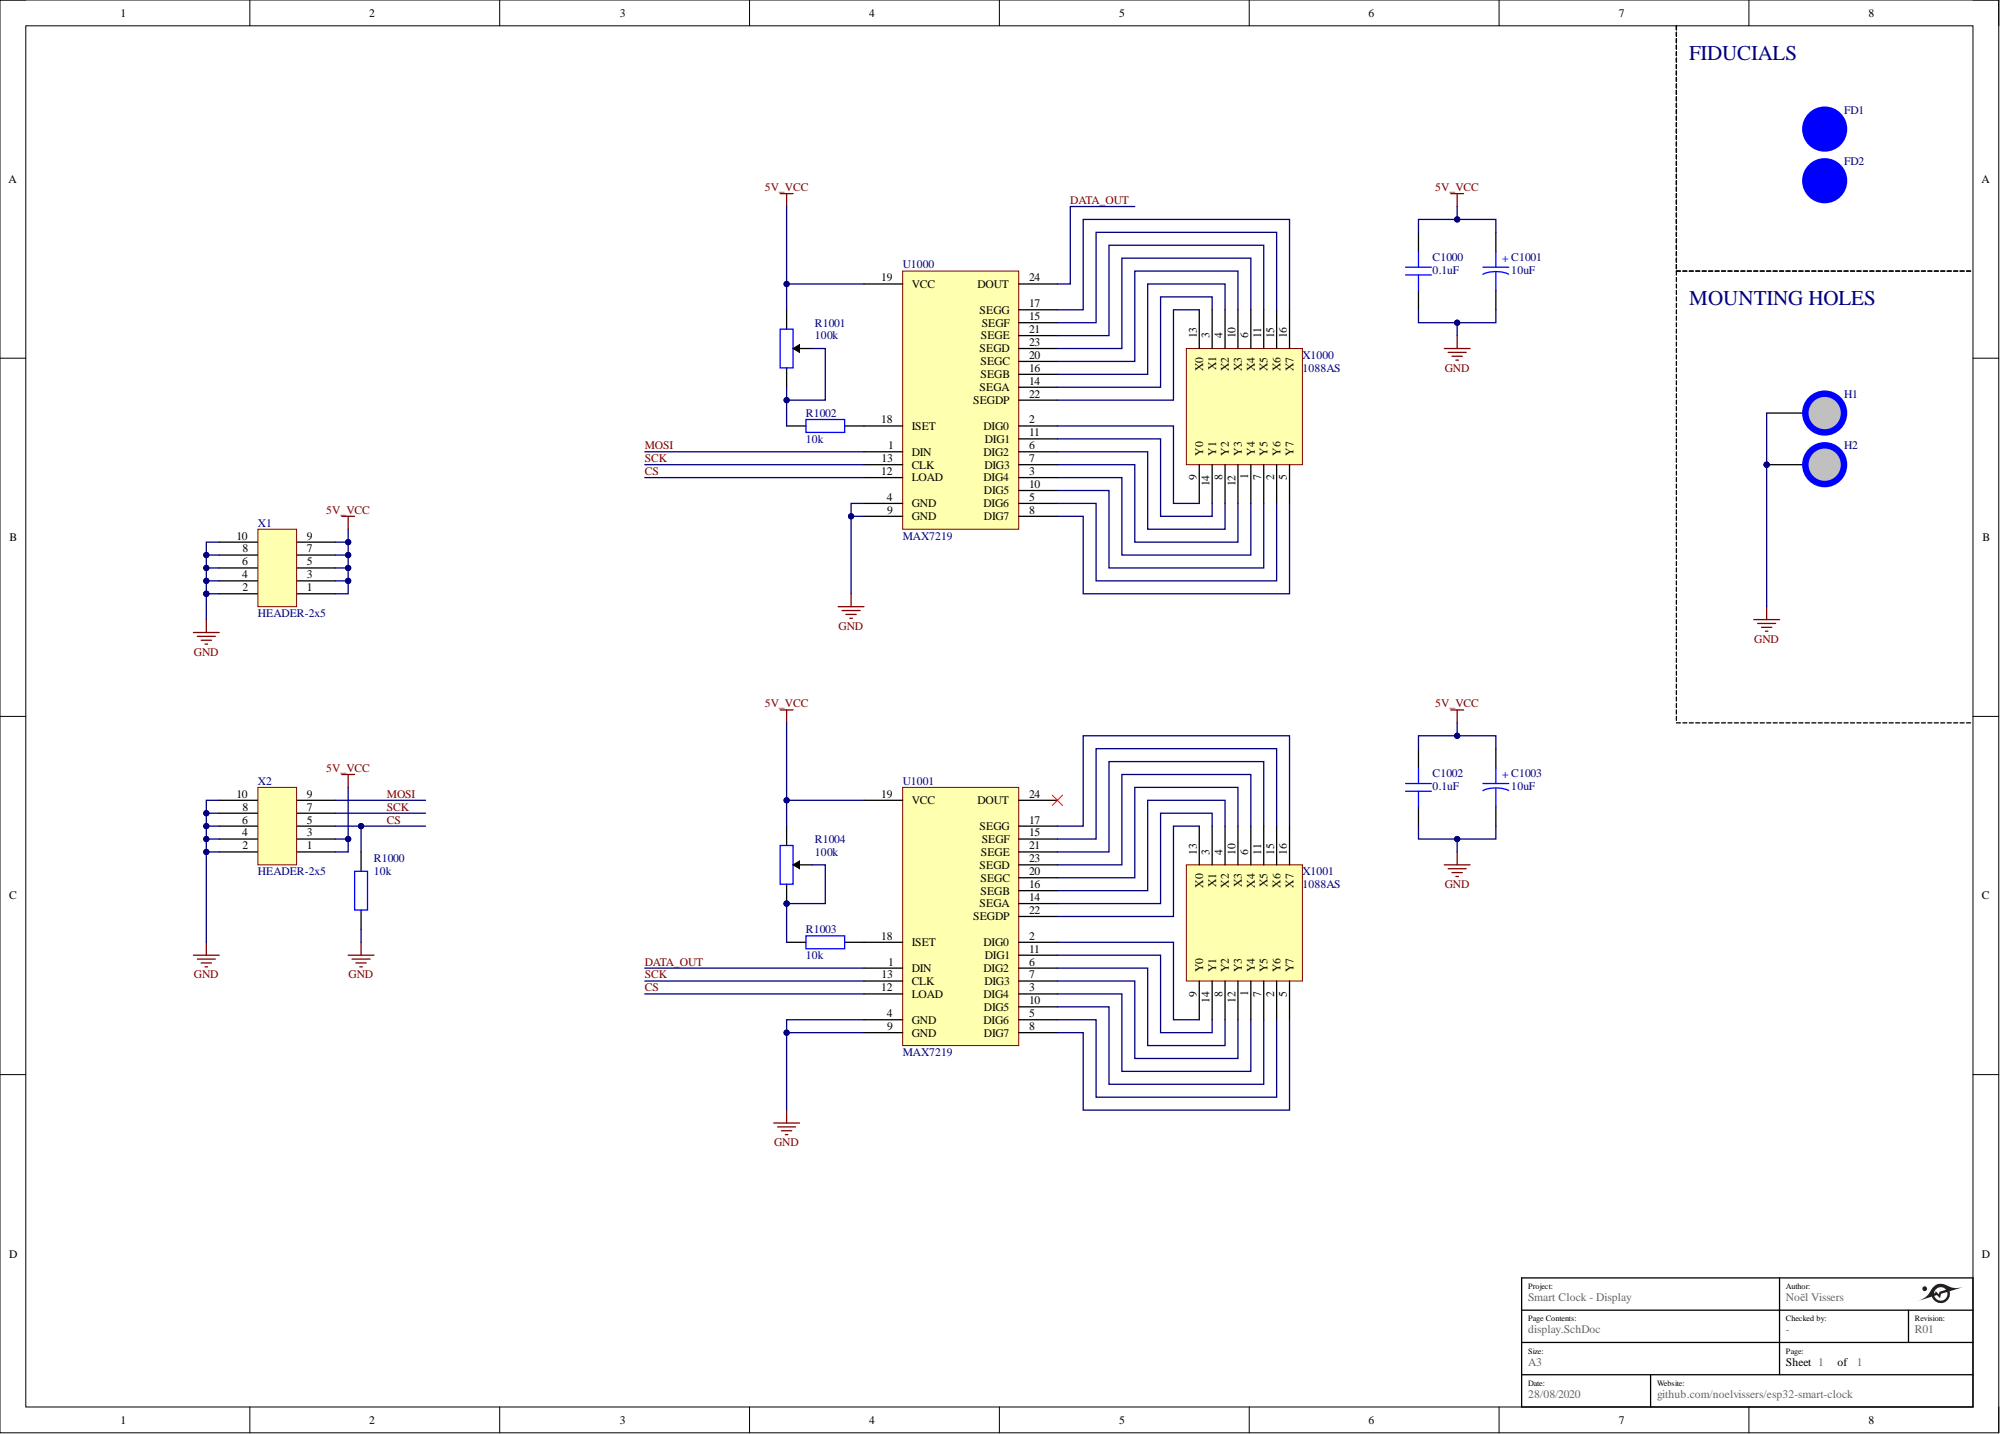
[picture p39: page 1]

ISET 18

GND 9

Project: Smart Clock - Display | Author: Noël Vissers

Page Contents: display.SchDoc | Checked by: - | Revision: R01

Size: A3 | Page: Sheet

Date: 28/08/2020 | Website: github.com/noelvissers/esp32-smart-clock

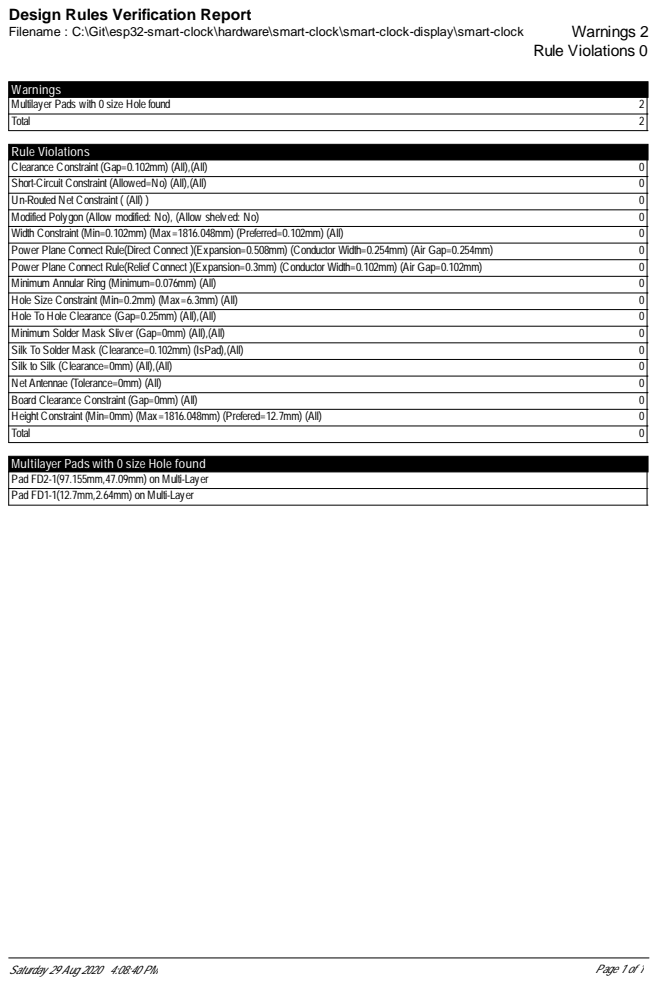
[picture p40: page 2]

Design Rules Verification Report

Multilayer Pads with 0 size Hole found
Pad FD2-1(97.155mm,47.09mm) on Multi-Layer
Pad FD1-1(12.7mm,2.64mm) on Multi-Layer

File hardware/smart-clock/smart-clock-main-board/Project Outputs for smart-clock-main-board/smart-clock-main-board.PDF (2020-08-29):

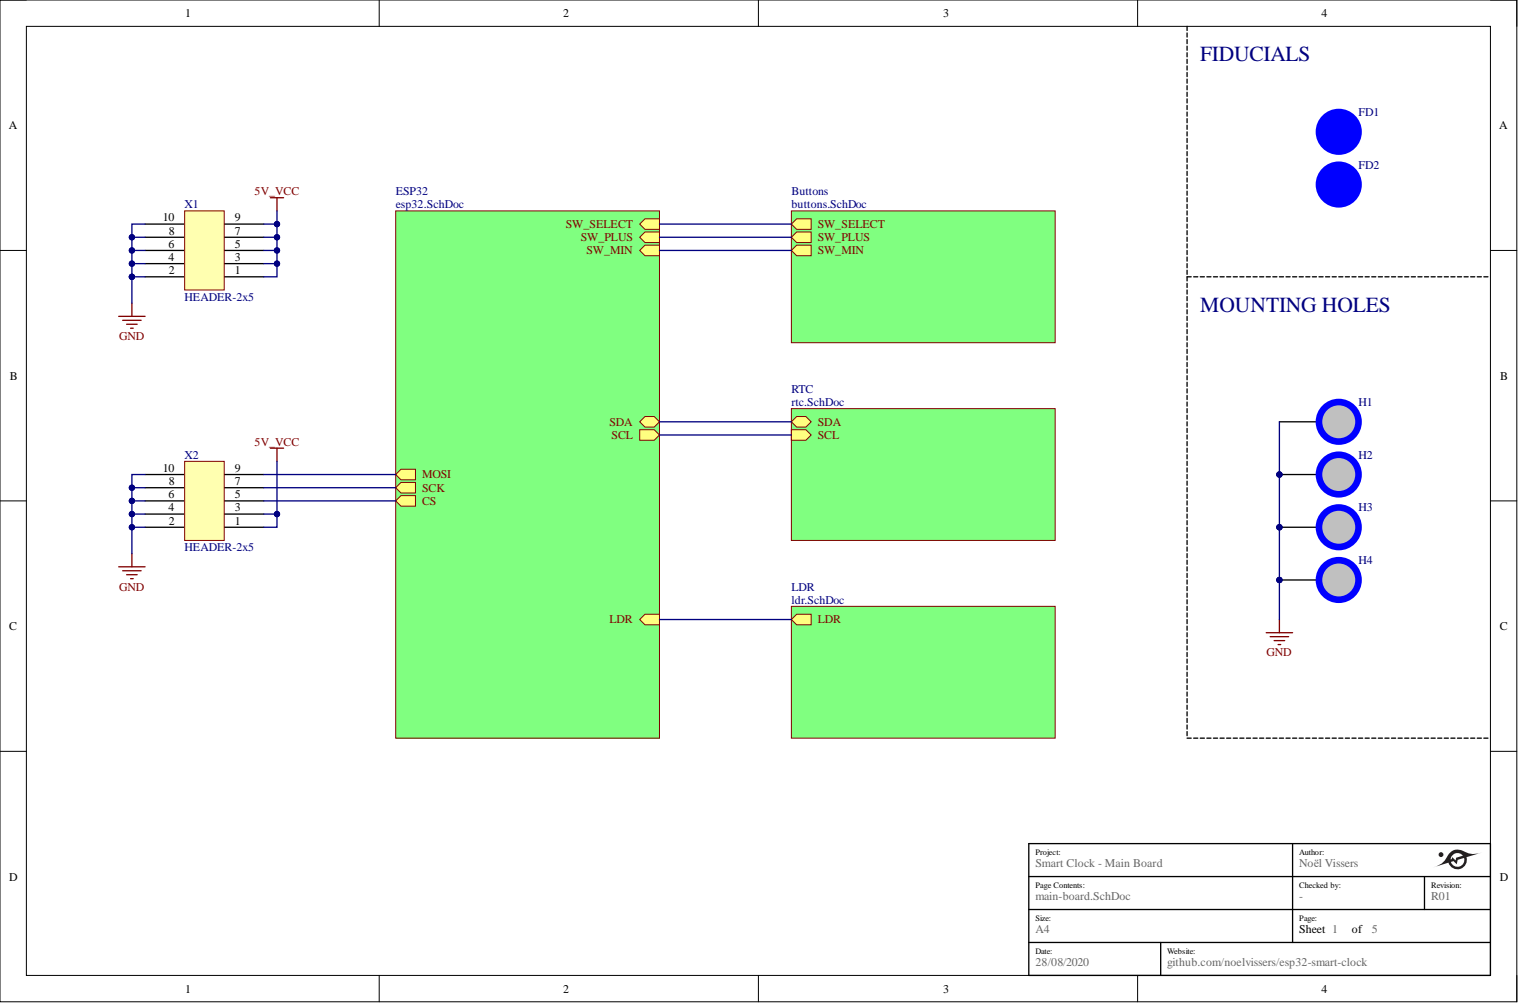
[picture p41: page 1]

Project: Smart Clock - Main Board | Author: Noël Vissers

Page Contents: main-board.SchDoc | Checked by: - | Revision: R01

Size: A4 | Page: Sheet

Date: 28/08/2020 | Website: github.com/noelvissers/esp32-smart-clock

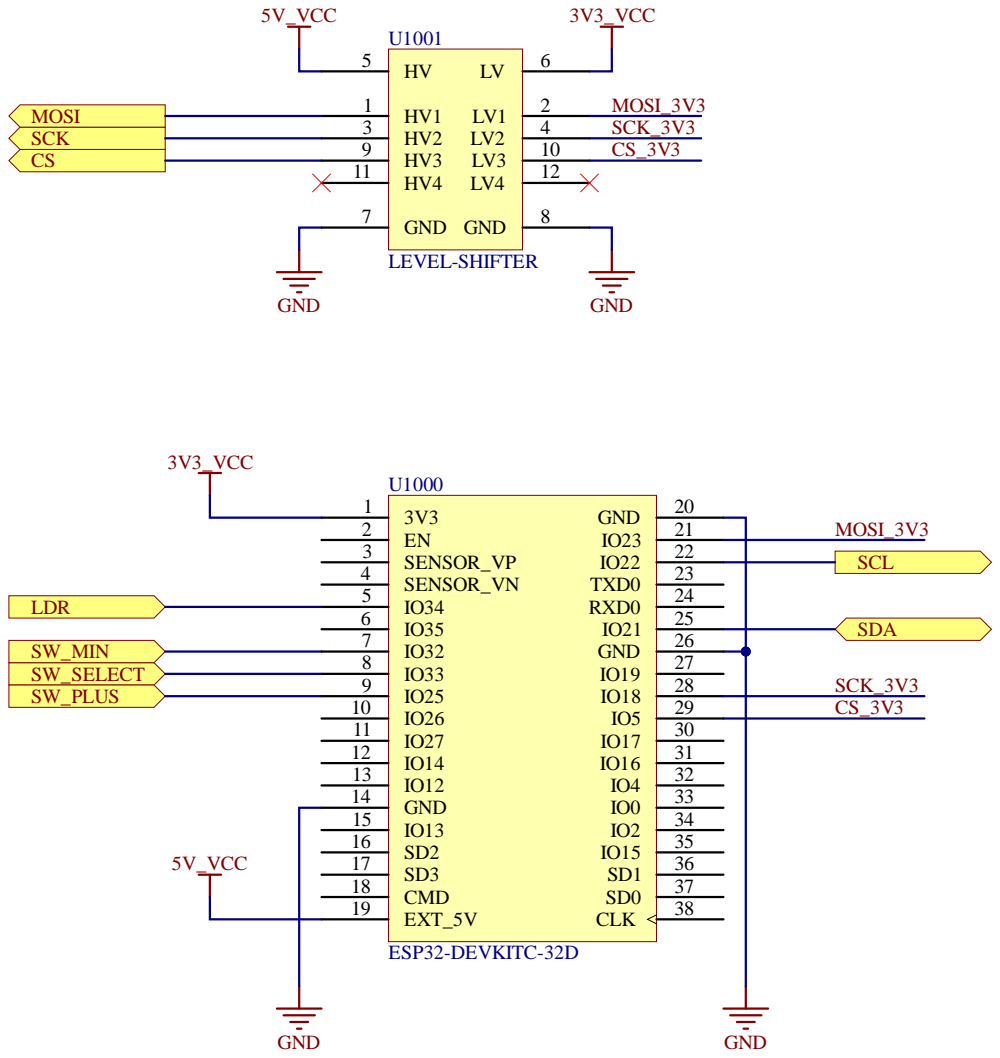
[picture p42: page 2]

Project: Smart Clock - Main Board | Author: Noël Vissers

Page Contents: esp32.SchDoc | Checked by: - | Revision: R01

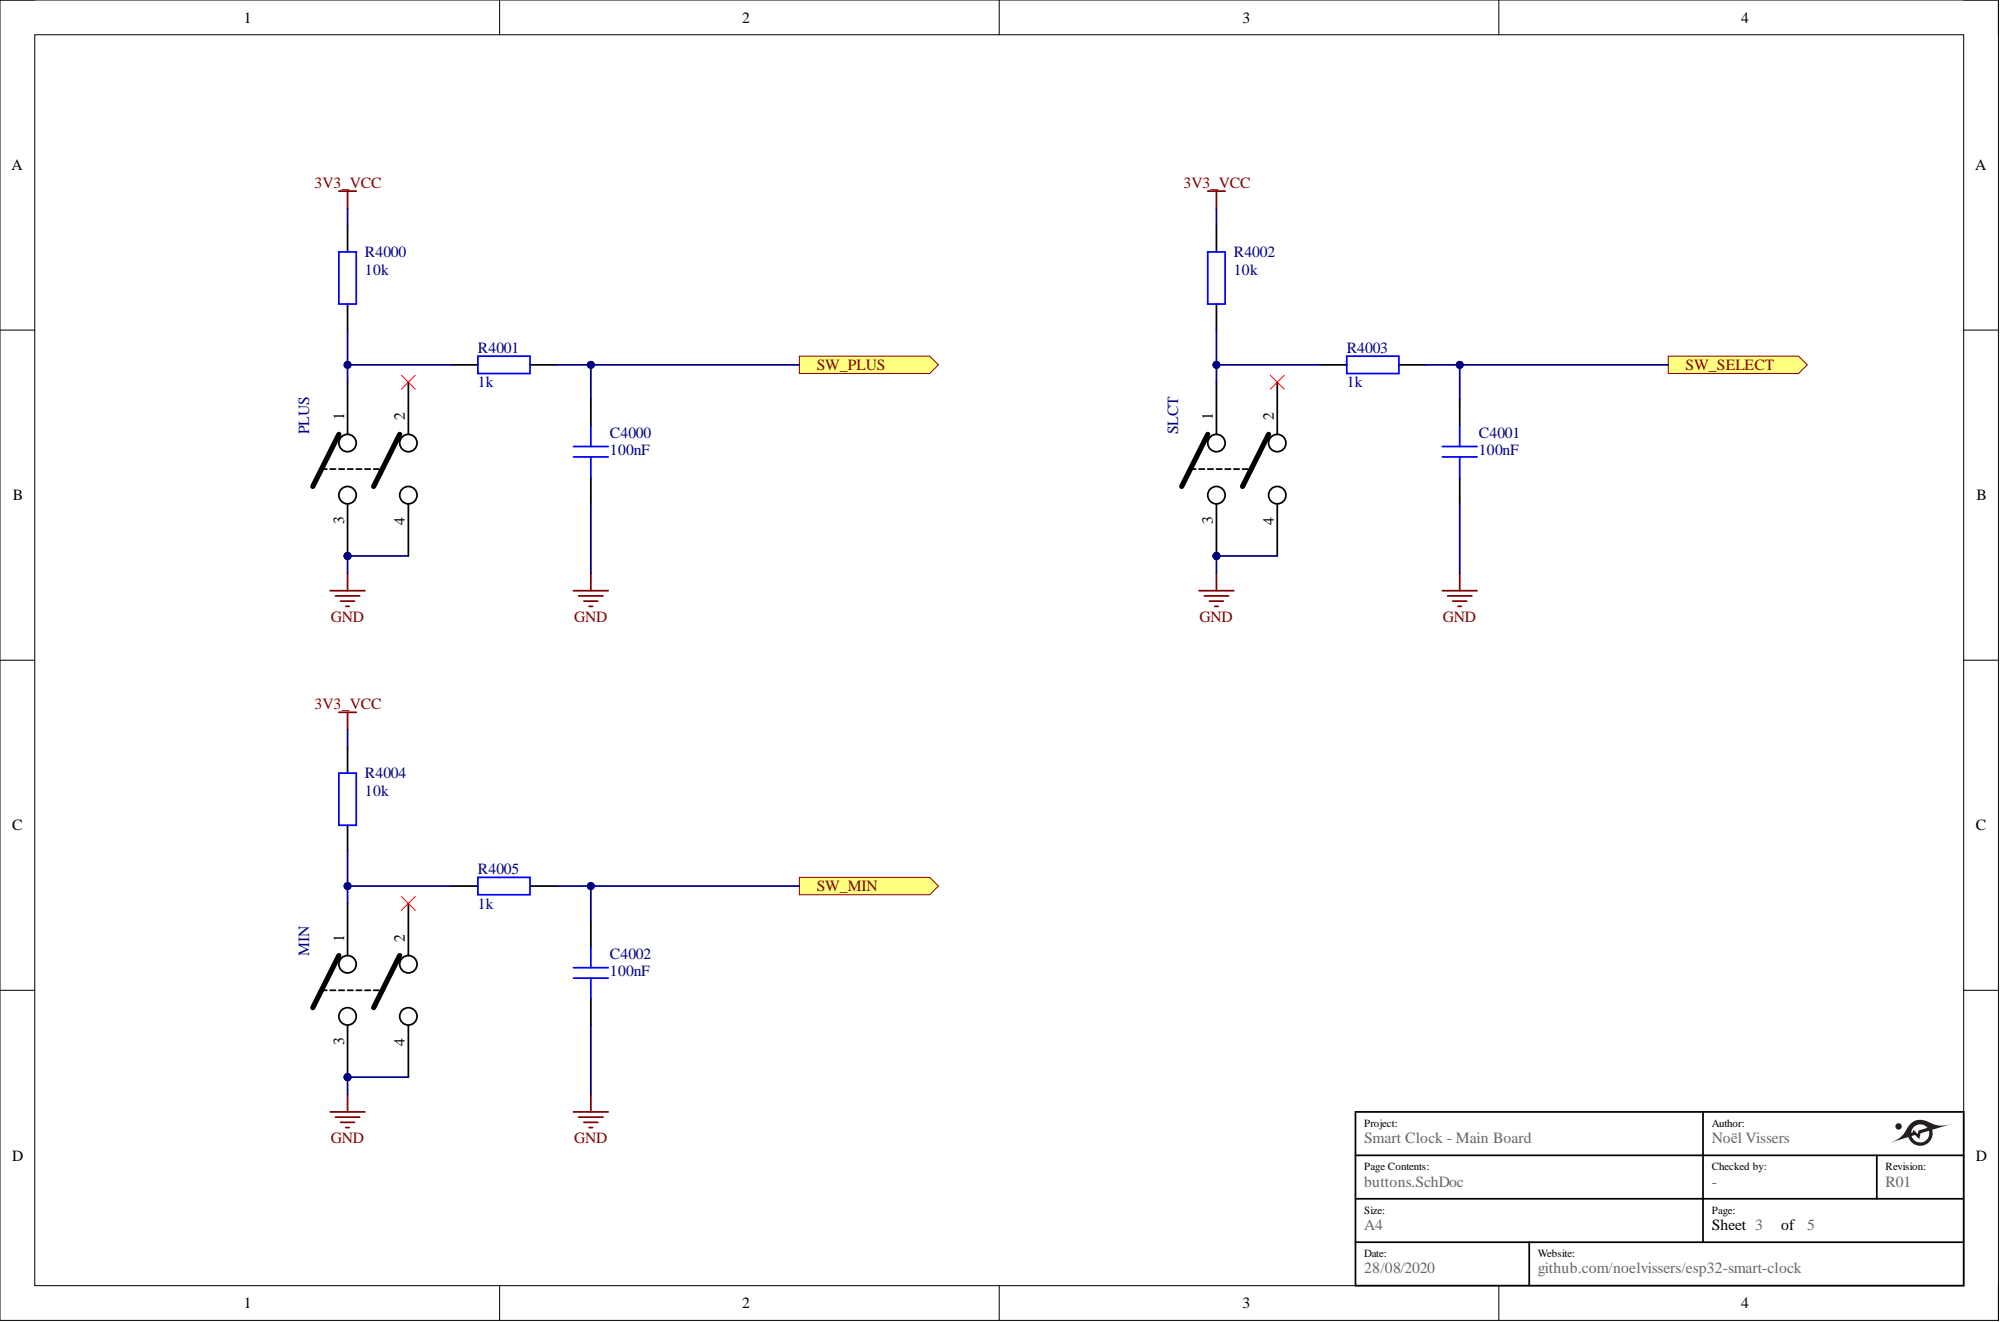
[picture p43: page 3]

Project: Smart Clock - Main Board | Author: Noël Vissers

Page Contents: buttons.SchDoc | Checked by: - | Revision: R01

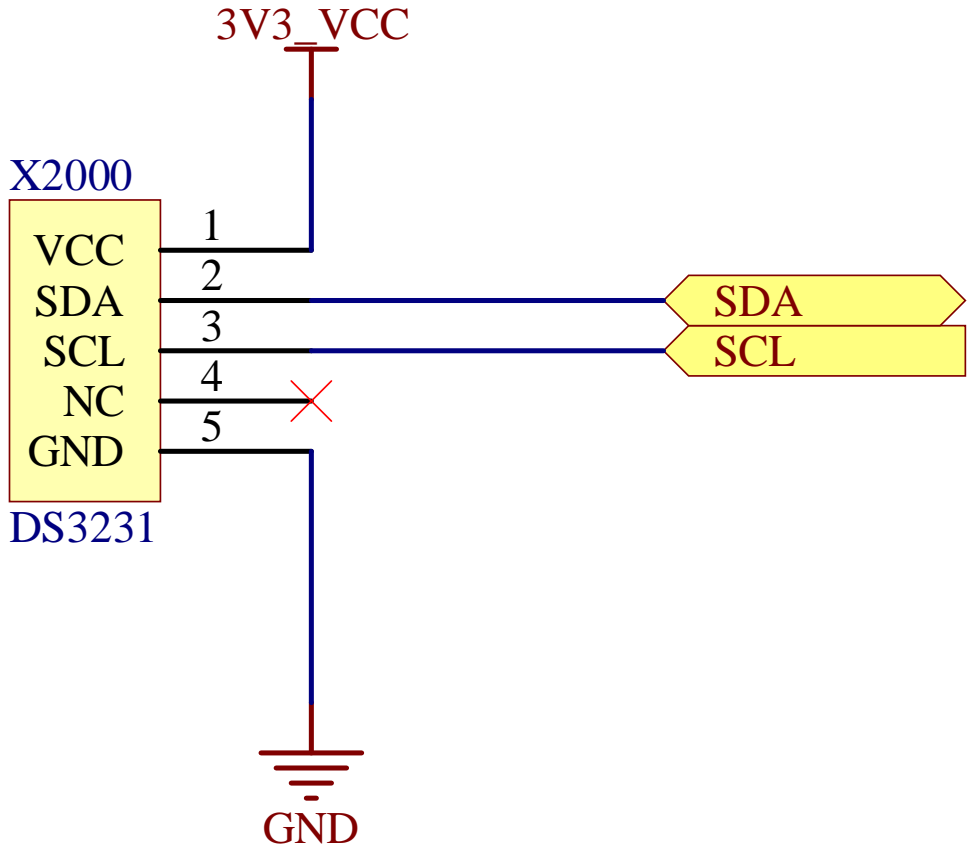
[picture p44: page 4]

Project: Smart Clock - Main Board | Author: Noël Vissers

Page Contents: rtc.SchDoc | Checked by: - | Revision: R01

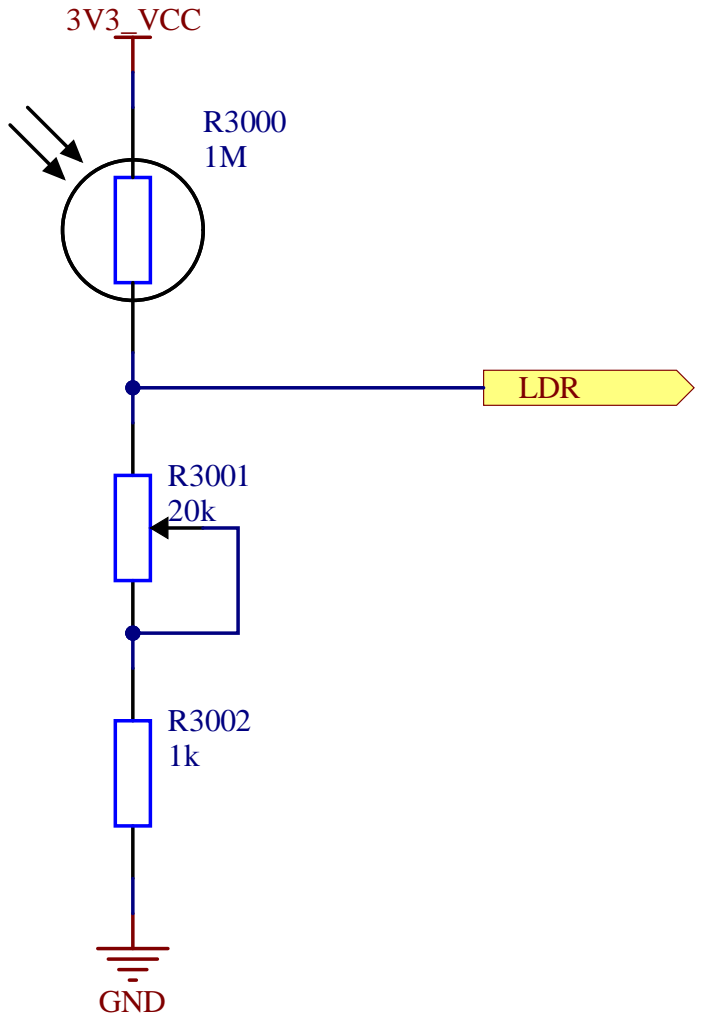
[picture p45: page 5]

Project: Smart Clock - Main Board | Author: Noël Vissers

Page Contents: ldr.SchDoc | Checked by: - | Revision: R01

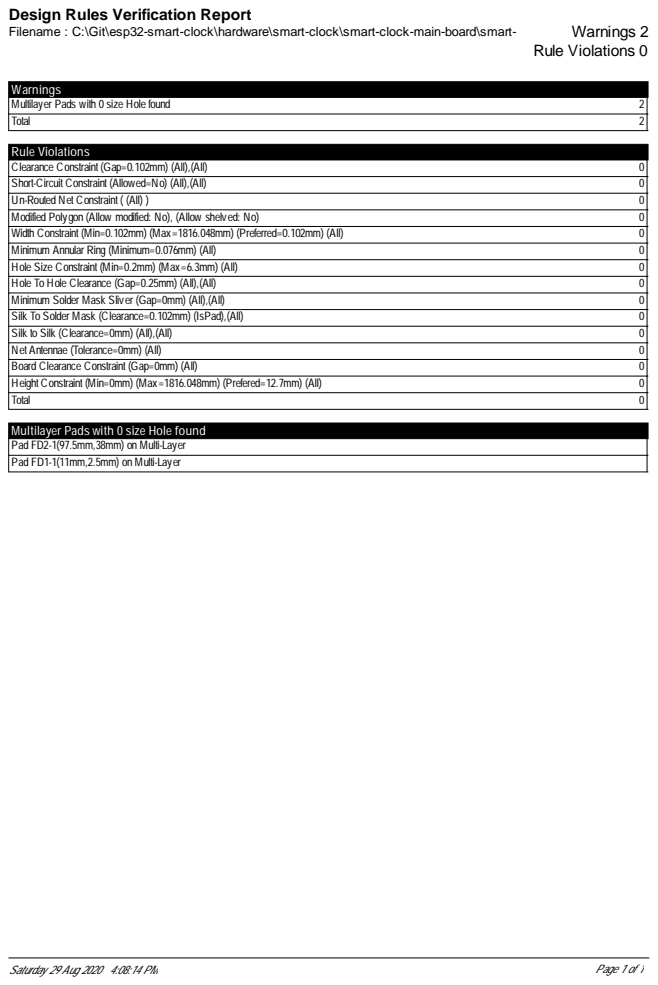
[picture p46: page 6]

Design Rules Verification Report

Multilayer Pads with 0 size Hole found
Pad FD2-1(97.5mm,38mm) on Multi-Layer
Pad FD1-1(11mm,2.5mm) on Multi-Layer

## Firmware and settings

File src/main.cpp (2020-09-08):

/**
 * @project       Smart Clock
 * @documentation https://github.com/noelvissers/esp32-smart-clock 
 */

#include <Arduino.h>
#include "config.h"
#include "display.h"
#include "network.h"
#include "weather.h"
#include "rtc.h"
#include "time.h"
#include "pong.h"

//create objects
TaskHandle_t TasksCore_0;
CConfig Config;
CDisplay Display;
CNetwork Network;
CWeather Weather;
CRtc Rtc;
CTime Time;
CPong Pong;

unsigned long lastAutoCycle = 0;
unsigned int state = 0;

//Main loop on core 0 (network functions)
void Core_0(void *parameter)
{
  for (;;)
  {
    delay(60000); //Do an update every minute
    if (!Weather.update())
    {
      Serial.println("[E][CORE_0] Error while updating weather.");
    }
    else
    {
      Serial.println("[CORE_0] Weather data received.");
    }

    if (!Time.update())
    {
      Serial.println("[E][CORE_0] Error while updating online time.");
    }
    else
    {
      Serial.println("[CORE_0] Syncing online time done.");
    }
  }
}

//ISRs//Buttons:
void IRAM_ATTR ISR_buttonPlus()
{
  if (!digitalRead(_pinButtonPlus)) //Chek if falling edge
  {
    if ((millis() - 25 > _lastButtonPlusPress) && !_buttonPlusPressed) //Debounce
    {
      //Set button states
      Serial.print("↓ ");
      _buttonPlusSet = true;
      _buttonPlusPressed = true;
      _lastButtonPlusPress = millis();
    }
  }
  else //Rising edge
  {
    if (_buttonPlusPressed) //Check if it was pressed to filter out false releases from bounce
    {
      Serial.print("↑ ");
      _buttonPlusPressed = false; //Reset button state
    }
  }
  _lastButtonPlusPress = millis();
}

void IRAM_ATTR ISR_buttonSelect()
{
  if (!digitalRead(_pinButtonSelect))
  {
    if ((millis() - 50 > _lastButtonSelectPress) && !_buttonSelectPressed)
    {
      Serial.print("↓ ");
      _buttonSelectSet = true;
      _buttonSelectPressed = true;
      _lastButtonSelectPress = millis();
    }
  }
  else
  {
    if (_buttonSelectPressed)
    {
      Serial.print("↑ ");
      _buttonSelectPressed = false;
    }
  }
  _lastButtonSelectPress = millis();
}

void IRAM_ATTR ISR_buttonMin()
{
  if (!digitalRead(_pinButtonMin))
  {
    if ((millis() - 25 > _lastButtonMinPress) && !_buttonMinPressed)
    {
      Serial.print("↓ ");
      _buttonMinSet = true;
      _buttonMinPressed = true;
      _lastButtonMinPress = millis();
    }
  }
  else
  {
    if (_buttonMinPressed)
    {
      Serial.print("↑ ");
      _buttonMinPressed = false;
    }
  }
  _lastButtonMinPress = millis();
}

void setup()
{
  //start serial communication for debugging
  Serial.begin(115200);
  Serial.println("[Status] Initializing...");

  //init classes
  Rtc.init();
  Config.initPinModes();
  Config.loadSettings();
  Display.init();

  EStatus statusNetwork = EStatus::Init;
  EStatus statusTime = EStatus::Init;
  EStatus statusWeather = EStatus::Init;
  Display.showStatus(statusNetwork, statusTime, statusWeather);
  Serial.println("[Status] Initializing [-][-][-]");
  delay(1000); //Add delay to show status on screen, or it will skip too fast

  //Setup network connection
  if (!Network.autoConnect())
  {
    statusNetwork = EStatus::Error;
    Serial.println("[E][Status] Error while configuring network.");
  }
  else
  {
    statusNetwork = EStatus::Done;
    Serial.println("[Status] Initializing [X][-][-] - Network configuration done.");
  }
  Display.showStatus(statusNetwork, statusTime, statusWeather);
  delay(1000); //Add delay to show status on screen, or it will skip too fast

  //Get Time
  Rtc.update();
  if (!Time.update())
  {
    statusTime = EStatus::Error;
    Serial.println("[E][Status] Error while configuring online time.");
  }
  else
  {
    statusTime = EStatus::Done;
    Serial.println("[Status] Initializing [X][X][-] - Syncing online time done.");
  }
  Display.showStatus(statusNetwork, statusTime, statusWeather);
  delay(1000); //Add delay to show status on screen, or it will skip too fast

  //Get Weather
  if (!Weather.update())
  {
    statusWeather = EStatus::Error;
    Serial.println("[E][Status] Error while configuring weather.");
  }
  else
  {
    statusWeather = EStatus::Done;
    Serial.println("[Status] Initializing [X][X][X] - Weather data received.");
  }
  Display.showStatus(statusNetwork, statusTime, statusWeather);

  //Create thread in core 0
  xTaskCreatePinnedToCore(Core_0, "TasksCore_0", 4096, NULL, 1, &TasksCore_0, 0);

  Config.saveSettings();

  //Attatch interrupts for buttons
  attachInterrupt(_pinButtonPlus, ISR_buttonPlus, CHANGE);
  attachInterrupt(_pinButtonSelect, ISR_buttonSelect, CHANGE);
  attachInterrupt(_pinButtonMin, ISR_buttonMin, CHANGE);

  Serial.println("[Status] Initializing done.");
  delay(1000); //Add delay to show status on screen, or it will skip too fast
  if ((statusNetwork == EStatus::Error) || (statusTime == EStatus::Error) || (statusWeather == EStatus::Error))
  {
    delay(4000); //add more delay if an error occured
  }
}

//Main loop on core 1
void loop()
{
  // Button checks
  if (_buttonPlusSet && _buttonMinSet && !_buttonSelectSet) //Both plus and min are pressed
  {
    while (_buttonPlusPressed && _buttonMinPressed)
    {
      if ((millis() - 3000) > _lastButtonPlusPress)
      {
        _buttonMinSet = false;
        _buttonSelectSet = false;
        _buttonPlusSet = false;

        Pong.start();
        break;
      }
    }
    _buttonMinSet = false;
    _buttonSelectSet = false;
    _buttonPlusSet = false;
  }
  else if (_buttonPlusSet && !_buttonMinSet && !_buttonSelectSet) //Only plus was pressed
  {
    bool hold = false;
    while (_buttonPlusPressed && !_buttonMinPressed)
    {
      if ((millis() - 3000) > _lastButtonPlusPress)
      {
        _autoBrightness = true;
        Display.showAutoBrightness();
        Serial.println("[Status] Autobrightness set.");
        Config.saveSettings();
        hold = true;
        break;
      }
    }
    if (!_buttonMinSet)
      _buttonPlusSet = false;
    _buttonSelectSet = false;
    if (!hold && !_buttonMinSet)
      Display.brightnessUp();
  }
  else if (!_buttonPlusSet && _buttonMinSet && !_buttonSelectSet) //Only min was pressed
  {
    bool hold = false;
    while (!_buttonPlusPressed && _buttonMinPressed)
    {
      if ((millis() - 3000) > _lastButtonMinPress)
      {
        _autoCycle = true;
        Display.showAutoCycle();
        lastAutoCycle = millis();
        Serial.println("[Status] AutoCycle set.");
        Config.saveSettings();
        hold = true;
        break;
      }
    }
    if (!_buttonPlusSet)
      _buttonMinSet = false;
    _buttonSelectSet = false;
    if (!hold && !_buttonPlusSet)
      Display.brightnessDown();
  }
  else if (!_buttonPlusSet && !_buttonMinSet && _buttonSelectSet) //Only select was pressed
  {
    while (_buttonSelectPressed)
    {
      if ((millis() - 5000) > _lastButtonSelectPress)
      {
        Serial.println("[I][Status] Resetting ESP...");
        Display.showReset();
        detachInterrupt(_pinButtonMin); //Without detach ESP crashes when releasing the button during reset.
        detachInterrupt(_pinButtonPlus);
        detachInterrupt(_pinButtonSelect);
        Network.resetSettings();
        Config.formatSettings();
        ESP.restart();
        for (;;)
          ;
      }
    }

    if (_autoCycle)
    {
      Serial.println("[Status] Turning off auto cycling...");
      _autoCycle = false;
      Config.saveSettings();
    }
    state++;
    _buttonMinSet = false;
    _buttonSelectSet = false;
    _buttonPlusSet = false;
  }
  else
  {
    _buttonMinSet = false;
    _buttonSelectSet = false;
    _buttonPlusSet = false;
  }

  switch (state)
  {
  case 0:
    Display.showTime();
    break;
  case 1:
    Display.showDate();
    break;
  case 2:
    Display.showTemperature();
    break;
  case 3:
    Display.showHumidity();
    break;
  /*
  case 4:
    Display.showTimeBin();
    break;
  */
  default:
    state = 0;
    break;
  }
  if ((((millis() - _autoCycleTime) > lastAutoCycle) && _autoCycle) && (millis() > _autoCycleTime))
  {
    lastAutoCycle = millis();
    state++;
  }
  delay(20);
}

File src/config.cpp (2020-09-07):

#include <Arduino.h>
#include "config.h"
#include "SPIFFS.h"
#include "ArduinoJson.h"

//Hardware settings:
uint8_t _pinButtonPlus = 25;
uint8_t _pinButtonSelect = 33;
uint8_t _pinButtonMin = 32;

uint8_t _pinDisplayMOSI = 23; //SPI_MOSI, Already auto defined in lc lib
uint8_t _pinDisplaySCK = 18;  //SPI_SCK, Already auto defined in lc lib
uint8_t _pinDisplaySS = 5;    //SPI_SS

uint8_t _pinStatusLed = 35; //Not used

uint8_t _pinRtcSCL = 22; //SCL, Already auto defined in rtc lib
uint8_t _pinRtcSDA = 21; //SDA, Already auto defined in rtc lib

uint8_t _pinLDR = 34; //Analog input

//General settings:
bool _autoBrightness = true;
bool _autoCycle = false;
bool _use24h = true;
bool _useDdmm = true;
bool _useCelcius = true;
unsigned long _autoCycleTime = 10000; //Time it takes to cycle to new view (ms)

//Button states:
unsigned long _lastButtonPlusPress = 0; //Last button press millis()
bool _buttonPlusPressed = false;        //Current state of button (resets on release)
bool _buttonPlusSet = false;            //Toggled state of button (resets when button action is done / manually)
unsigned long _lastButtonSelectPress = 0;
bool _buttonSelectPressed = false;
bool _buttonSelectSet = false;
unsigned long _lastButtonMinPress = 0;
bool _buttonMinPressed = false;
bool _buttonMinSet = false;

//Weather settings:
char _weatherCityName[64] = "";
char _weatherCountryCode[3] = "";
char _weatherEndpoint[64] = "http://api.openweathermap.org/data/2.5/weather?q=";
char _weatherApiKey[64] = "";

//Time settings:
char _timeEndpoint[64] = "http://worldtimeapi.org/api/ip";

//Display settings:
uint16_t _ldrLowerLimit = 0;   //0 min ADC/LDR (making this value higher means the display reaches its min brightness sooner)
uint16_t _ldrUpperLimt = 4095; //4095 max ADC/LDR (making this value higher, lowers the max brightness | making this value lower means the display reaches its max brightness sooner)
int _ldrError = 125;           //Schmidt trigger threshold

//Set pinmodes for IO
void CConfig::initPinModes()
{
  pinMode(_pinButtonPlus, INPUT);
  pinMode(_pinButtonSelect, INPUT);
  pinMode(_pinButtonMin, INPUT);
  pinMode(_pinStatusLed, OUTPUT);
}

//Save all settings to memory
bool CConfig::saveSettings()
{
  Serial.println("[Config] Saving...");

  if (SPIFFS.begin(true)) //Start SPIFFS
  {
    File fSettings = SPIFFS.open("/config.json", FILE_WRITE); //Open file in write mode

    DynamicJsonDocument doc(1024); //Create temp. document to store string data in from SPIFFS

    //Save settings
    //General settings
    doc["general"]["autoBrightness"] = _autoBrightness;
    doc["general"]["autoCycle"] = _autoCycle;
    doc["general"]["useDdmmFormat"] = _useDdmm;
    doc["general"]["use24hFormat"] = _use24h;
    doc["general"]["useCelciusUnit"] = _useCelcius;

    //Weather settings
    doc["weather"]["weatherCityName"] = _weatherCityName;
    doc["weather"]["weatherCountryCode"] = _weatherCountryCode;
    doc["weather"]["weatherApiKey"] = _weatherApiKey;

    serializeJson(doc, fSettings); //Convert doc objects to strings and put them in fSettings file
    fSettings.close();             //Close file

    Serial.println("[Config] Saving done.");
    return true;
  }
  else
  {
    Serial.println("[E][Config] An error occurred while mounting SPIFFS.");
  }
  return false;
}

//Load all settings from memory
bool CConfig::loadSettings()
{
  Serial.println("[Config] Loading...");

  if (SPIFFS.begin(true)) //Start SPIFFS
  {
    if (SPIFFS.exists("/config.json")) //Check if file exsists on drive
    {
      File fSettings = SPIFFS.open("/config.json", FILE_READ); //Open file in read only mode

      DynamicJsonDocument doc(1024);                                //Make temp. document to store string data in from SPIFFS
      DeserializationError error = deserializeJson(doc, fSettings); //Convert strings from fSettings to objects and put them in doc
      if (!error)                                                   //Chech if no errors occured while converting to objects
      {
        //Load all settings, so that in network config the saved values are showed. If they're empty it means they need to be filled in.
        //General settings
        if (doc["general"]["autoBrightness"])
          _autoBrightness = doc["general"]["autoBrightness"];
        else
          _autoBrightness = false;

        if (doc["general"]["autoCycle"])
          _autoCycle = doc["general"]["autoCycle"];
        else
          _autoCycle = false;

        if (doc["general"]["useDdmmFormat"])
          _useDdmm = doc["general"]["useDdmmFormat"];
        else
          _useDdmm = false;

        if (doc["general"]["use24hFormat"])
          _use24h = doc["general"]["use24hFormat"];
        else
          _use24h = false;

        if (doc["general"]["useCelciusUnit"])
          _useCelcius = doc["general"]["useCelciusUnit"];
        else
          _useCelcius = false;
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

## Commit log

2020-08-01 Add ArduinoJson to lib_deps, Remove OTA
2020-08-01 Namechanges and SPIFFS fixes
    [main.cpp, network.cpp, weather.cpp]
2020-08-02 Bug fix for saving/loading settings
    [config.cpp, main.cpp, time.cpp]
2020-08-03 Implement button interrupt + debounce
2020-08-03 Fix memory issue for Core_0
    [config.cpp, main.cpp, weather.cpp]
2020-08-03 Add buttons and menu
2020-08-06 First implementation of button functions
2020-08-06 Change serial prints to DEBUG info for normal information
2020-08-06 Change DEBUG to DEBUGGING since it was interfering with other lib
    [config.cpp, display.cpp, main.cpp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]
2020-08-06 Remove buttonhandler (this is done in main.cpp)
2020-08-06 Button bugfixes
2020-08-09 Fix boolians in save file
    [config.cpp, main.cpp, network.cpp]
2020-08-17 Fix network settings saving/reading
    [config.cpp, main.cpp, network.cpp]
2020-08-22 Add hardware files
    [1x5 Male Pin Header.STEP, 1x6 Male Pin Header Angle.stp, 2x10 Male Pin Header Angle.STEP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]
2020-08-23 Add component library
    [DS3231 - NO HEADER.step, smart-clock-pcblib.PcbLib, smart-clock-schlib.SchLib]
2020-08-24 Update hardware files
    [LEVEL SHIFTER.step, MAX7219.step, TH Capacitor - 0.1uF.step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]
2020-08-24 Add Altium Project
    [buttons.SchDoc, display.SchDoc, esp32.SchDoc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]
2020-08-26 Comment LED since it is not used
2020-08-26 Update schematics
    [buttons.SchDoc, display.SchDoc, esp32.SchDoc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]
2020-08-26 Make PCB layout
    [buttons.SchDoc, display.SchDoc, esp32.SchDoc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]
2020-08-26 Update components
    [TH LDR.step, smart-clock-pcblib.PcbLib, smart-clock-schlib.SchLib]
2020-08-28 Add schematic info
    [buttons.SchDoc, display.SchDoc, esp32.SchDoc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]
2020-08-28 Add fabrication outputs, fix pinout display connector
    [buttons.SchDoc, display.SchDoc, smart-clock-display.PcbDoc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]
2020-08-29 Add output file
    [smart-clock-display.GBL, smart-clock-display.GBO, smart-clock-display.GBS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]
2020-09-07 Add assembly drawing
2020-09-07 Fix pong bug, change ''
    [config.cpp, display.cpp, main.cpp]
2020-09-08 Bug fixes, remove auto DST
    [display.cpp, main.cpp]
